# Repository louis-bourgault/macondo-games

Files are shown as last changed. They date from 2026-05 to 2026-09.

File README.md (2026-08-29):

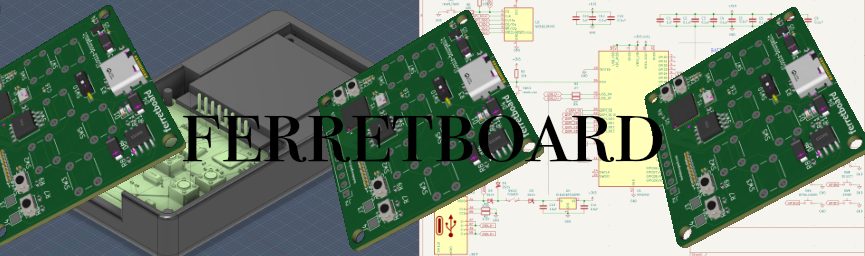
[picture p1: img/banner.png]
banner

# ferretboard!!!

> [!IMPORTANT]
> # PLEASE READ
> The primary documentation for this project can be found at [ferretboard.louisbourgault.com/docs](https://ferretboard.louisbourgault.com/docs). Please read from that source for organised information on software interfaces, assembly, and a more complete project overview.
> 
> This README remains the authoritative source on commands to build the firmware for the device, and also has a nice image gallery at the end.



# What is this?
Ferretboard is a simple games console, made to be easy to program and cheap to produce. Version one uses a RP2040 MCU; version two, currently in development, upgrades this to the RP2350 and changes the form factor significantly. The display is a 240x240 1.54" LCD, which is common and cost effective. It is battery powered, using a basic 3.7v LiPo.

The idea for this project, in the long term, is to be an easy introduction to programming and game development for students. The micropython sdk is editable in web, easy to get started using, and would be perfect in the long run for a classroom setting or Hack Club larger program. The upgrade to the RP2350 will make this level of software possible, with more RAM and processing power to make running complicated games within Micropython possible. 

The overall dimensions of the build are around 100x50mm for both v1 and v2, with a depth of around 20mm. The case is 3d printed.

This is made as a part of Hack Club Macondo. You can find my project at [macondo.hackclub.com/projects/1137](https://macondo.hackclub.com/projects/1137). Thank you to Hack Club for financing and helping me with this project. You can find all acknowledgements for this project at [ferretboard.louisbourgault.com/thanks](https://ferretboard.louisbourgault.com/thanks)

## Online stuff!
Docs site and main site: [ferretboard.louisbourgault.com](https://ferretboard.louisbourgault.com)
Web editor for the micropython sdk: [editor.louisbourgault.com](https://editor.louisbourgault.com)

## Project Structure
See at [ferretboard.louisbourgault.com/docs/structure](https://ferretboard.louisbourgault.com/docs/structure)

# Building Firmware
There's quite a few different firmwares at this point to build. Docs on how to do each of them:

[Original Go System](https://ferretboard.louisbourgault.com/docs/go-building)
[New micropython system (embedded into Go)](https://ferretboard.louisbourgault.com/docs/micropython-building)
[Old micropython system](https://ferretboard.louisbourgault.com/docs/oldmp-build)

To flash firmware on v2, hold down the reset button and reboot the device. On v1, manually short QSPI_SS and GND with tweezers and then reboot. The easiest access points for this are the first and last pins of the flash chip on the top side - you can just pinch the top of the flash chip, and that should do it.

Then, either use picotool over command line, or just drag the uf2 file into the RPI-RP2 volume that shows up in Finder/File Explorer/Dolphin/whatever you use.

# Assembly instructions
Assembly instructions can be found at [ferretboard.louisbourgault.com/docs/assembly](https://ferretboard.louisbourgault.com/docs/assembly).

# Gallery

The full gallery can be found at [ferretboard.louisbourgault.com/gallery](https://ferretboard.louisbourgault.com/gallery). Here is just a few sample images: 

## The micropython online editor working!
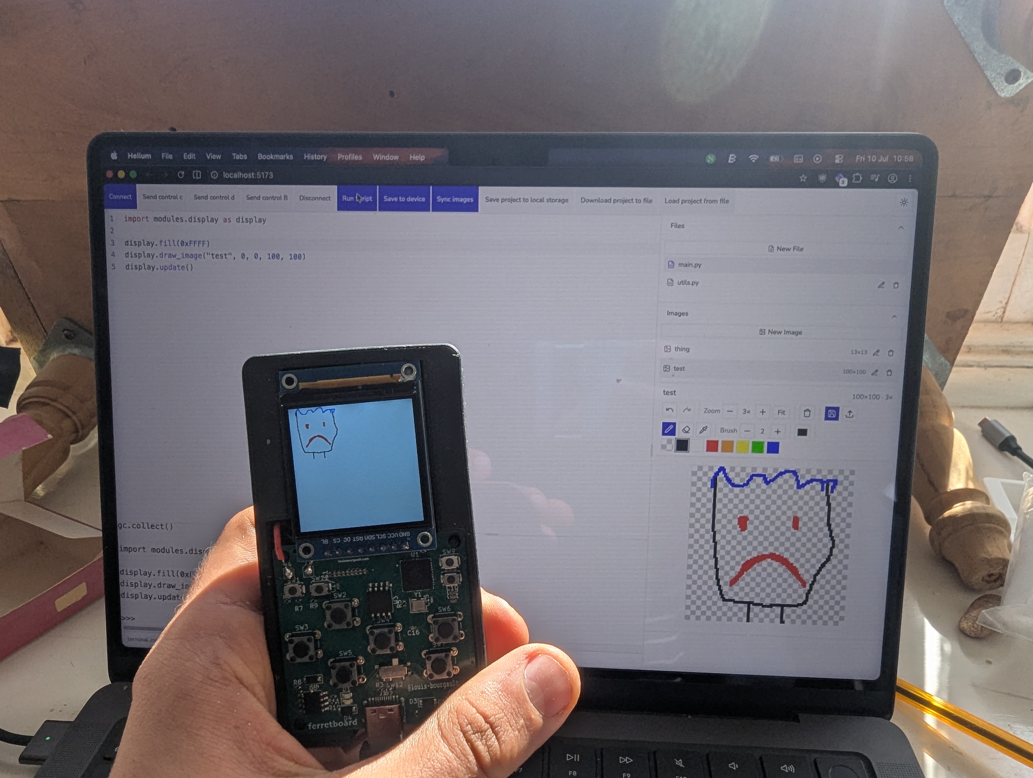
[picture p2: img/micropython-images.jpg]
micropython image system


## Finished Device (v1)
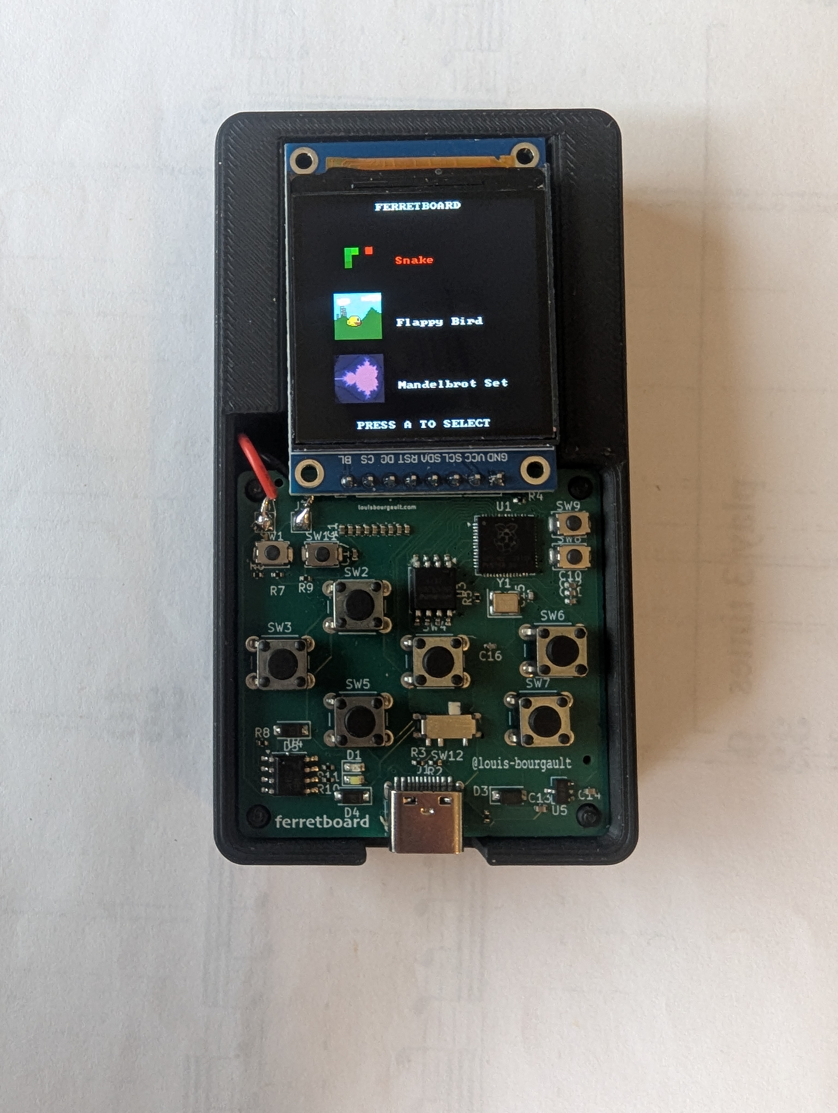
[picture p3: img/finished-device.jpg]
Finished device


## Fusion design for new version (not produced yet)
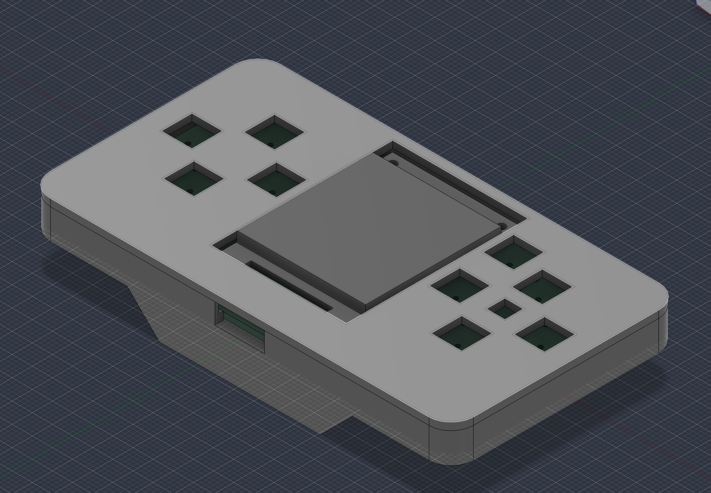
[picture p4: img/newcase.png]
New Version


# Acknowledgements

Find all acknowledgements at [ferretboard.louisbourgault.com/thanks](https://ferretboard.louisbourgault.com/thanks)

Font file used in /software/helpers/text.go - Public Domain, [github.com/dhepper/font8x8](https://github.com/dhepper/font8x8/blob/master/font8x8_basic.h)

framebuf2 - MIT Licenced, https://github.com/peter-l5/framebuf2

codemirror v6 - MIT Licenced, https://code.haverbeke.berlin/codemirror/dev/ 

# Licensing

This project is dual-licensed:
* **Hardware:** The schematic, PCB layout, and documentation files are licensed under the [CERN Open Hardware Licence v2 - Strongly Reciprocal (CERN-OHL-S-2.0)](./mini-games/LICENSE.txt). If you modify and distribute this hardware, you must share your changes to it. 
* **Firmware/Software:** All source code is licensed under the [GNU AGPLv3](./LICENSE.txt). You can't copy and distribute a changed version of this without making your modifications public, including distribution by serving a part of this code over a network. [Even if you're Bambu Labs.](https://consumerrights.wiki/w/Bambu_Lab_cease_and_desist_against_OrcaSlicer_fork_developer)

# Looking for something?
Looking for something, like assembly instructions or something else? Please check the link up the top of this readme.

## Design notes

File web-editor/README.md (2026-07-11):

# Web Editor
This repository is a feature complete web editor for the python sdk of the board, which includes a multifile code editor (based on the excellent codemirror library), image sprite editor with transparency, and terminal. The system connects to the device over USB using the browser WebSerial API.

## Stack

This web app uses a simple typescript setup comprising of:
- Svelte
- Sveltekit
- UI library: shadcn-svelte
- codemirror

There is no database or backend component, and this can be entirely run statically by building sveltekit to the static adapter.

To program a device using this sdk, you must have a device flashed with the micropython sdk, which can be found at /mp-sdk at the top level of this repository. Follow the instructions in that README for instructions on building and flashing this firmware.

## Running locally

Install modules and run:

```bash
pnpm install

pnpm run dev
```

Then open your browser to localhost:5173 to test.

## Requirements
The web serial api is not supported by Safari or Firefox. Use a recent version of a chromium based browser.

## Licence
As with all other code components in this repository, this module is licenced under the [GNU AGPL](../LICENSE.txt)

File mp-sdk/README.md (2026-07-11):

# uploading to the device
it doesn't work just hitting run in vs code: hit all commands and then do micropico: upload project to pico from command/control shift p

# Building instructions:
## Setup - what you need installed on your computer (macOS, likely very similar on linux, if you're on windows use WSL)
If you're on linux, all you'll need to change is to install the packages below with your distro's package manager

```zsh
brew install --cask gcc-arm-embedded
brew install cmake ninja
```

next, clone the micropython git repository and compile some things

```zsh
git clone https://github.com/micropython/micropython.git
cd micropython
make -C mpy-cross

cd ports/rp2
make submodules
```

Note: once you're at this stage, you can use the script ```build.sh``` in this repository to build it. Note, you will have to adapt this script to where everything is on your machine, so its probably easier to just do the commands manually.

## Building
Hop into the ```ports/rp2``` directory inside your micropython git clone.

```zsh
# delete old build cache
rm -rf build-ferretboard

#run the build command with paths to the board directory and the manifest.py. For me this is
make BOARD_DIR=/Users/louisb/Documents/hardware/macondo-games/mp-sdk/boards/ferretboard FROZEN_MANIFEST=/Users/louisb/Documents/hardware/macondo-games/mp-sdk/boards/ferretboard/manifest.py

```

This will output a uf2 file in the ```ports/rp2/build-ferretboard/``` directory inside the micropython repo, which you can then copy onto the device. If you're using the script as i am, it will instead copy it directly into this repository.

# Licences
This software itself is AGPL licenced. 

Acknowledgement is also given to the framebuf2 library, which makes up an integral part of this repository. This component is licenced under a MIT licence.

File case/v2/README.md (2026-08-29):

## The files in here:

- casev2.f3d/.step - the case, on its own. does not include cad model of screen or pcb
- st7789_display.f3d/.step - model of the display that I use. Took me a decent amount of time to model, so i'm including it.
- fbv2_including_pcb_and_screen.f3z - an archive file including all the component parts. this uses multiple fusion files from seperate components, as well as the PCB, imported from Kicad. What all the screenshots are of, but not neccesary for the case design - hence no step files. Also, multi file exports get annoying from Fusion
- 3dp/ - the production STL files for the upper and lower sections of the case. Put these into your slicer.

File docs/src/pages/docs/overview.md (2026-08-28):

---
layout: '../../layouts/DocsLayout.astro'
title: 'Project Overview'
draft: false
category: "general"
---

# Ferretboard!!!

Ferretboard is a small games console based around a custom pcb and a 1.54" SPI display. Version one uses the RP2040 chip. Version two is currently in development, and upgrades this to the RP2350 with a significantly different board and case. The overall dimensions of both versions are around 50x100x20mm, so a relatively typical size for a handheld.

This device is being made as part of Hack Club Macondo (which is awesome). You can find it at [macondo.hackclub.com/projects/1137](https://macondo.hackclub.com/projects/1137).

Another major element of this project is that the Go game system is also compatible with being built for web assembly. A demo of this can be found at the root of this website.

## Components
The finished version one system is made up of a custom pcb, including the RP2040 chip, 16MB of flash memory, and a battery management circuit. It also uses:
- 3.7v 1000mAh LiPo
- 1.54" LCD Screen of pixel dimensions 240x240 and with an SPI interface
- 6 basic 6x6x5 push to make switches for the d-pad, A and B
- 2 smaller buttons on the assembled pcb for Start and Exit
- 3d printed case, the stl file for which is in ```/case/v1/case.stl``` in the repository

The version two KiCad project can be found in ```/hardware-v2```, and its case files are in ```/case/v2```. It is still a work in progress, so the assembly instructions are for version one unless they specifically say otherwise.

## Controls
The system has a basic d-pad, as well as A and B buttons as the primary controls. There are also two buttons (called Start and Exit in software) for other purposes, but it is better to not use them as primary game controls since they are smaller and more annoying to access.

For the WASM version, these are mapped to:
| Button | Key |
| --- | --- |
| D-Pad  | WASD |
| A | J |
| B | K |
| Start | Enter |
| Exit | Shift |

## Constraints
The RP2040 has its hardware constraints, although most games will fit very comfortably within them. It is a dual core cpu rated for 133MHz, with 264KB of SRAM. A considerable amount of this ram is used for the display buffer: 115,200 bytes, or 112.5KiB, since we use full 16 bit colour. This leaves around 149KiB before the rest of the firmware and runtime allocations are taken into account.

Another constraint that I discovered through working on this is that the RP2040 does not have a FPU (floating point unit). This means that it takes a ton of cpu cycles to do any float division and multiplication, so we need to make sure to stay with integers for as much as possible.
This is a problem for maths visualisations like the Mandelbrot and Julia set, which probably will not run very well, if at all, on the actual device unless optimised further.

The flash storage is 16MB. The current embedded MicroPython firmware reserves the last 8MB for its LittleFS filesystem, with the first 8MB left for the firmware. There is plenty of overall flash for this kind of project, but individual MicroPython source files and images have smaller limits that are explained in the MicroPython reference.

## This website
This website is made with Astro, and no external libraries, and can be found in the ```/docs``` folder of the repository.

## Acknowledgements
Font file used in /software/internal/helpers/text.go: [github.com/dhepper/font8x8](https://github.com/dhepper/font8x8/blob/master/font8x8_basic.h). (Public domain)

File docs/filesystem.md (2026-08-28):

# The Ferretboard Filesystem

The Ferretboard runs a LittleFS2 volume at `/` on the last 8 MiB of its
16 MiB QSPI flash. Students see it as plain Python files:

```python
>>> f = open("hello.txt", "w")
>>> f.write("hello ferret")
>>> f.close()
>>> print(open("hello.txt").read())
```

This document explains how that works: the flash layout, the layers between
`open()` and the silicon, and the gotchas that had to be solved to get there.

## Architecture

The firmware is Go (TinyGo, RP2040/RP2350) hosting a MicroPython interpreter.
Go owns the hardware; MicroPython owns the student-facing runtime. The
filesystem spans that boundary:

```
Python  open() / os.listdir()
   │
   ▼
MicroPython VFS layer                 (extmod/vfs.c)
   ▼
VfsLfs2 driver                         (extmod/vfs_lfs.c — LittleFS2)
   │  readblocks / writeblocks / ioctl
   ▼
"Flash" block device object           (port/flash_storage.c)
   │  ferret_flash_read/write/erase/block_count/block_size  (//export)
   ▼
Go flashBlockDev                      (flash_common.go)
   │  ReadAt / WriteAt / EraseBlocks / Size
   ▼
raw flash backend
   ├─ device: machine.Flash           (flash_device.go — bootrom flash API)
   └─ host:   file-backed stub        (flash_stub.go  — NOR emulation)
```

## Flash layout

The chip is a 16 MiB W25Q128-class QSPI flash, memory-mapped at
`0x1000_0000` (XIP). The image is laid out as:

| Region | XIP address | Notes |
|---|---|---|
| boot2 | `0x1000_0100` | 256 bytes, second-stage bootloader |
| firmware (code+data) | `0x1000_0100` + | ~330 KB |
| **filesystem** | last 8 MiB of chip | 2048 blocks × 4 KiB |

The boundary between firmware and filesystem is computed at runtime, not
hard-coded:

- TinyGo's linker (`targets/arm.ld`) defines `__flash_data_start` (end of the
  program image) and `__flash_data_end` (end of the whole flash window) from
  `__flash_size`.
- `setupFlashRegion()` (`flash_device.go`) reads those symbols via
  `machine.FlashDataStart()/FlashDataEnd()` and places the FS region at
  `regionBase = rawTotalSize - 8 MiB`, i.e. ~7.6 MiB into the chip.

`__flash_size` comes from the target JSON. This is important:

```json
// ferretboard.json
"ldflags": ["--defsym=__flash_size=16M"]
```

`just device` builds with `-target ferretboard.json`. The stock `pico` target
uses `__flash_size=2048K`, which makes `regionBase` negative — the firmware
panics with "firmware larger than first 8 MiB of flash" before the REPL ever
appears (symptom: no serial output at all; the boot delay + stage traces we
added temporarily made it visible).

## Block device (Go side)

`flashBlockDev` (`flash_common.go`) presents the FS region as a zero-based
block device with 4 KiB blocks, hiding `regionBase` from its consumers. The
4 KiB size matches the flash erase sector, so LittleFS2 operations align with
hardware erases.

Key constants:

```go
flashBlockSize   = 4096   // erase sector == LFS2 block
flashStorageBytes = 8 MiB // reserved FS region
writePage        = 256    // NOR page-program granularity
```

`WriteAt` pads partial writes to whole 256-byte pages with `0xFF` before
calling the raw backend (`flash_common.go:76`). This is safe because NOR
programming only clears bits and LittleFS2 only writes into erased sectors,
so padding bytes are always `0xFF` no-ops.

### Device backend — `machine.Flash`

TinyGo's RP2040 flash driver (`machine_rp2_flash.go`):

- `ReadAt`: reads the memory-mapped XIP window directly (`unsafe.Slice` over
  `0x1000_0000 + off`).
- `WriteAt` / `EraseBlocks`: call the bootrom's `flash_range_program` /
  `flash_range_erase` tables (`machine_rp2040_rom.go`). The bootrom functions
  must run from RAM, which the driver handles; they also flush the XIP cache.

### Host backend — `stubbedFlash`

The PC reference build (`just host`) models the chip as a plain file
(`build/ferret.img`, overridable with `FERRET_FS_IMAGE`), initialised to
`0xFF` so erased reads behave like real flash. It is a debugging tool, so it
emulates NOR semantics faithfully:

- `WriteAt` does a read-modify-**AND**: programming a byte yields
  `existing & new`. A plain file overwrite would corrupt data, because
  LittleFS2 programmes a 4 KiB block in several 256-byte page-prog calls and
  the later ones would clobber the earlier ones. This exact bug corrupted the
  volume during development (formatted fine, then `open()` returned garbage
  or the mount failed after writes).
- `EraseBlocks` fills with `0xFF`.

## MicroPython side (C)

`port/flash_storage.c` wraps the `//export` funcs in an MP block device
object (`Flash` with `readblocks`/`writeblocks`/`ioctl`) and bootstraps the
volume:

```c
void ferret_fs_init(void) {
    if (!ferret_flash_has_fs()) {
        ferret_fs_format();       // first boot only
    }
    mp_obj_t bdev = ...&ferret_flash_obj;
    args[0] = mp_call_function_n_kw(&mp_type_vfs_lfs2, 1, 0, &bdev);
    args[1] = MP_OBJ_NEW_QSTR(qstr_from_str("/"));
    mp_vfs_mount(2, args, &mp_const_empty_map);
}
```

- **First-boot detection**: `ferret_flash_has_fs()` reads block 0 and checks
  for the `"littlefs"` superblock name at offset 8. A blank chip (all `0xFF`)
  has none, so it is formatted with `lfs2_format` first.
- **Mounting**: `VfsLfs2`'s `make_new` mounts eagerly, so instantiating
  `VfsLfs2(flash)` and passing it to `mp_vfs_mount("/", ...)` does the whole
  job. `mp_vfs_lfs2_make_new` is `static` in `vfs_lfs.c`, hence the
  roundabout `mp_call_function_n_kw` on the type object.
- **Soft reset**: `run_repl()` (host.c) re-runs `mp_embed_init` → registers
  the `ferret` module → `ferret_fs_init()` on every Ctrl-D, re-mounting `/`
  on the same volume.

The `ioctl` handler returns `BLOCK_COUNT`/`BLOCK_SIZE` from the Go exports
and `0` for INIT/DEINIT/SYNC. `readblocks`/`writeblocks` accept the optional
offset argument (block-level + sub-block offset) — both are summed correctly
in `ferret_flash_read/write` (`block*4096 + off`), no double counting.

## Boot flow (device)

```
bootrom → boot2 → Reset_Handler
  → runtime.init()          USB CDC enumerates here (before main!)
  → main()                  display init
  → setupFlashRegion()      FS region math (needs __flash_size=16M)
  → ferret_boot()           point MP's GC at mpHeap
  → run_repl()
      mp_embed_init
      register_ferret_module
      ferret_fs_init()      detect/format/mount "/"
      pyexec_friendly_repl  ">>> " banner
```

The REPL prompt only appears after the volume is mounted. If the mount
fails, the board looks dead even though USB is fine.

## Building and testing

```sh
# PC reference build — interactive MP REPL over a file-backed flash image
just host   # -> ./spike

# Device build — 16 MiB target, LittleFS2 region at ~7.6 MiB
just device # -> ferret.uf2  (flash with: picotool load ferret.uf2 -f)
```

`MICROPYTHON_ROOT=/path/to/micropython` must be set (the justfile's
`mp-arm`/`mp-host` recipes regenerate the embed package, genhdr and the
`libmp_embed*.a` archives; `gen_cgo.sh` bakes the archive fingerprints into
`z_cgo_link_*.go` — it re-runs after `ar rcs` so Go's build cache never
links a stale archive).

## Gotchas discovered along the way

1. **Wrong `__flash_size` (the "no serial at all" bug).** Building with the
   stock `pico` target (2 MiB) while the region math assumes 16 MiB made
   `regionBase` negative → immediate panic, before any USB output appeared.
   Fix: build with `ferretboard.json` (`__flash_size=16M`).
2. **TinyGo interp panic.** `machine.FlashDataStart()/End()` inside an
   `init()` function made the compile-time interpreter fold the
   `__flash_data_end` pointer constant and panic ("cannot convert pointer
   value to byte"). Fix: call them from `main()` via `setupFlashRegion()`
   — the interp only folds `*.init` functions.
3. **`mp_call_method_n_kw` hang.** Instantiating `VfsLfs2` must use
   `mp_call_function_n_kw(&mp_type_vfs_lfs2, 1, 0, &bdev)`, not
   `mp_call_method_n_kw` (which treated `&mp_type_vfs_lfs2` as a `self` and
   hung at boot).
4. **`ioctl` arity.** `t_flash_ioctl` must be `FUN_OBJ_3` (it takes
   self/cmd/arg); `FUN_OBJ_2` left the arg slot unset and `BLOCK_COUNT`
   returned garbage → mount failed.
5. **Probe offset.** The LFS2 superblock magic/name sits at offset 8 of
   block 0, not 16 — an off-by-one made every boot think the volume was
   unformatted and re-format it (data loss on every reboot).
6. **NOR write semantics (host).** The stub's plain-file overwrite did not
   emulate "program only clears bits", so padded page-progs clobbered
   earlier progs in the same 4 KiB block. Fixed with read-modify-AND.
7. **Fingerprint ordering.** `gen_cgo.sh` ran before the archives were
   rebuilt, so its md5 was one build behind; Go's cache then linked stale
   C objects. Fixed by re-running it after `ar rcs` in `mp-arm`/`mp-host`.

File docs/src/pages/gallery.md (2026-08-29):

---
layout: '../layouts/DocsLayout.astro'
Title: Image Gallery
draft: false
---

# V1 design

schematic

finished device

fusion case design

with parts included

case, but in white

jlc design

# SDK on web

images in the sdk, working on the device

# Version Two

new case

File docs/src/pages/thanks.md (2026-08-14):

---
layout: '../layouts/DocsLayout.astro'
Title: Thanks and Acknowledgements
draft: false
---

# Thanks and Acknowledgements
## Hack Club
The biggest acknowledgement here. I made this for Hack Club Macondo, an awesome hackathon. They funded the build, and even bought me rewards for the hours i put in.
Hack club helps teens learn to do coding and electronics.
[https://hackclub.com](https://hackclub.com)

## Open Source
Font file used in /software/helpers/text.go - Public Domain, [github.com/dhepper/font8x8](https://github.com/dhepper/font8x8/blob/master/font8x8_basic.h)

framebuf2 - MIT Licenced, https://github.com/peter-l5/framebuf2

codemirror v6 - MIT Licenced, https://code.haverbeke.berlin/codemirror/dev/

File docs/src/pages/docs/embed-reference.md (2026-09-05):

---
layout: '../../layouts/DocsLayout.astro'
title: 'MicroPython SDK - Embedded Reference'
draft: false
category: "mp"
---

The firmware exposes a single ```ferret``` module with all drawing, input and
helper functions built in. Import it at the top of your game script with:

```python
import ferret
```

All colours are RGB565 integers; use ```ferret.rgb_to_565(r, g, b)``` to build
one from 8-bit channels. The screen is 240x240 pixels.

## Drawing

Drawing calls update a frame buffer in RAM. Call ```ferret.present()``` to
send it to the screen.

### ```ferret.pixel```
Arguments: x, y, colour.

Draws a single pixel.

### ```ferret.fill_rect```
Arguments: x, y (top left corner), width, height, colour.

Draws a filled rectangle.

### ```ferret.fill```
Argument: colour.

Fills the whole screen with a single colour. Useful to clear the frame
between frames.

### ```ferret.draw_text```
Arguments: text, x, y, colour.

Draws text at the top-left coordinate x, y. A single character is 8x8.

### ```ferret.measure_text```
Argument: text. Returns (width, height).

Measures the space text will take up, so you can centre it.

### ```ferret.draw_image```
Arguments: image_name, x, y.

Draws an image stored on the device at (x, y). The size is read from the image
manifest, so sync your images from the web editor first. Transparent pixels use
the RGB565 chroma key colour ```0xF81F``` and are skipped (if you are using the 
web editor, this is done automatically for transparent pixels). No image can be
over 240x240 pixels.

### ```ferret.present```
No arguments.

Flushes the frame buffer to the display.

## Input

Call ```ferret.input_update()``` once per frame **before** checking buttons.
Key names are strings. Both boards provide "A", "B", "UP", "DOWN", "LEFT"
and "RIGHT". Version one additionally provides "START" and "EXIT"; version
two provides "X", "Y" and "MENU" instead.

### ```ferret.input_is_pressed```
Argument: key name. Returns a bool.

True if the key is currently held.

### ```ferret.input_was_just_pressed```
Argument: key name. Returns a bool.

True if the key is pressed this frame but was not last frame.

### ```ferret.input_was_just_released```
Argument: key name. Returns a bool.

True if the key was pressed last frame but is not this frame.

## Helpers

### ```ferret.rgb_to_565```
Arguments: r, g, b. Returns an RGB565 colour.

### ```ferret.random_int```
Arguments: min, max. Returns a random integer in the inclusive range [min, max].

## Example

```python
import ferret

while True:
    ferret.input_update()
    if ferret.input_was_just_pressed("A"):
        ferret.fill(ferret.rgb_to_565(255, 0, 0))
        ferret.present()
```

## Files and editor functions (not user facing, you should not need these)

The editor also uses ```ferret.write_file_b64```, ```ferret.append_file_b64```,
```ferret.file_manifest```, ```ferret.delete_file```,
```ferret.write_image```, ```ferret.append_image```,
```ferret.write_image_end```, ```ferret.image_manifest``` and
```ferret.delete_image``` to save code and sync images. Games do not normally
need to call these functions themselves. A single file is currently limited to
16KiB. Normal Python ```open()``` and ```os``` filesystem access is not included.

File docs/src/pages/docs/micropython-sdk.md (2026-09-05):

---
layout: '../../layouts/DocsLayout.astro'
title: 'MicroPython SDK (new) - About'
draft: false
category: "mp"
---

The current MicroPython SDK is the main scripting system for the console. You write your code in the web editor at ```/web-editor``` in the repository, which is deployed at [editor.louisbourgault.com](https://editor.louisbourgault.com).

The intention of this system is to provide an easy entry to the console. I am first writing this with my idea being to give these devices to a school as a way to teach students to code, or at least to pitch the idea to a teacher. I think that having an easy to code system that runs fully in a browser without having to install anything is pretty cool, personally.

This is different to the [legacy MicroPython SDK](/docs/micropython-sdk-legacy). The current firmware has a Go backend which controls the display, input and filesystem, with MicroPython embedded into it and a thin C glue layer in the middle. Student programs use the ```ferret``` module to call into that backend.

## Using the editor

The editor uses Web Serial, so you need a recent Chromium-based browser such as Chrome or Edge, and the page must be loaded over HTTPS or localhost. Safari and Firefox do not currently support Web Serial.

Every project has a ```main.py``` file, which is run automatically when the device starts or soft resets. Other ```.py``` files can be imported from ```main.py```. Their names must be valid Python identifiers followed by ```.py``` (for example, ```player.py```). Start programs by importing the SDK:

```python
import ferret
```

The editor can create multiple code files, draw and import images, show the serial terminal, save a project in browser storage, and download or load the complete project as a JSON file. Connect the device, then use **Run Script** to synchronize the project's code files to flash (including removing files deleted or renamed in the editor) and soft reset into the new ```main.py```. Images are sent separately with **Sync Images**.

See the [embedded reference](/docs/embed-reference) for the functions available to games, and the [building guide](/docs/micropython-building) for making the firmware itself.

## Included Python modules

The firmware intentionally includes a fairly small set of Python modules. The most useful ones for games are ```time```, ```math```, ```struct```, ```array```, ```collections```, ```gc``` and ```sys```. Normal Python filesystem functions such as ```open()``` and ```os.listdir()``` are not included in the current system; code and images are managed by the Go backend and the web editor.

images in the sdk, working on the device

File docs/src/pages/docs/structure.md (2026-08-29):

---
layout: '../../layouts/DocsLayout.astro'
title: 'Project Structure'
draft: false
category: "general"
---

## File structure

## Project Structure
- /software - all software for the Go game system and the current embedded MicroPython firmware
- /software/cmd/embed - the current Go-hosts-MicroPython firmware and its build system
- /mini-games - The kicad project and files for the version one hardware
- /hardware-v2 - The kicad project and files for the version two RP2350 hardware, which is still in development. Its JLC files are under /hardware-v2/jlcpcb/production_files.
- /case - files for making the cases. Version one and version two are in their own subdirectories.
- /img - the images used in the main readme
- /docs - this website
- /mp-sdk - the legacy MicroPython SDK and its custom MicroPython board definition
- /mp-embedding - an early experiment used while working out how to embed MicroPython into Go
- /web-editor - the web editor for the current embedded MicroPython SDK.

Production files: production files can be found at /jlcpcb/production-files in both the mini-games and hardware-v2 directories, for the v1 and v2 design respectively. These are automatically generated with the jlcpcb tools plugin in kicad, and use LCSC numbers for BOM and CPL. 

Big thanks to the plugin: [Bouni/kicad-jlcpcb-tools](https://github.com/Bouni/kicad-jlcpcb-tools)

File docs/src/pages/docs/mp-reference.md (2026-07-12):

---
layout: '../../layouts/DocsLayout.astro'
title: 'Micropython SDK - Quick Reference'
draft: false
category: "mp"
---

The micropython sdk contains two main modules - ```modules.display``` and ```modules.input```. Import them at the top of your file with:

```python
import modules.display as display
import modules.input as input
```

## Display

### General shape
To make changes to the display, call the following functions to update the frame buffer in RAM. Then call ```display.update()``` to send the data to the screen.

All colours are in RGB565 format.

### ```display.pixel```
Arguments: x, y, colour.

Draws a single pixel to the screen

### ```display.rect```
Arguments: x, y (top left corner), width, height, colour.

Draws a rectangle to the screen

### ```display.text```
Arguments: text, x, y, colour

Draws text to the screen at top left coords of x and y. A single character is size 8x8.

### ```display.draw_image```
Arguments: image_name, x, y, image_width, image_height

Draws an image stored in ```/img``` in the device's flash to the screen. As of now, the logic cannot infer the image width and height, so you must explicitly pass them. This my change in future.
When you upload an image from the web editor, it is automatically placed in this directory.

### ```display.update```
No arguments.

Flushes data to the display.

## Input
The input module deals with button presses. 

### General shape
Call ```input.update``` to check all the buttons, and update state (this includes moving the store of current button presses to last button presses). Call this **before** you do any input handling in your main game loop

Key names are strings, and are "A", "B", "UP", "DOWN", "LEFT" and "RIGHT"

### ```input.is_pressed```
Argument: key name

Returns a boolean on whether it is currently pressed

### ```input.was_just_pressed```
Argument: key name

Returns true if the key is pressed this frame but was not last frame.

### ```input.was_just_released```
Argument: key name

Returns true if the key was pressed last frame but was not this frame.

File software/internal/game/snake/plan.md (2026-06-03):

# What is this?
A plan on how to code snake. I want to try and figure out the logic without any copilot or anything.
i want this to be more efficient than it needs to be. 

main struct
- current direction
- slice of {x,y} coordinates
  - can't use normal slices since we'll be constantly adding to the end and taking away from the start, and exhaust ram by just moving the pointer forwards a ton
  - apparently a ring buffer is a thing. I think i'll choose this - it comes out to 1.1kb of ram for the whole thing
  - linked list

params
- board width: 24*24, cells 10 pixels each

color 
- changes colour depending on which level it is in

rgb565 colours - format of RRRRRGGGGGGBBBBB where each one is a number

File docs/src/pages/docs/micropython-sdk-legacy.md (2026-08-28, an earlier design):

---
layout: '../../layouts/DocsLayout.astro'
title: 'MicroPython SDK (legacy) - About'
draft: false
category: "ogmp"
---

Apart from the golang sdk, there is also a micropython sdk. This is designed for ease of use, even to go so far as to be an introduction to programming.
This came about after I showed this project to a digital technologies teacher at my school, and he was somewhat interested in how something like the device could be used in a school setting due to its simplicity and people being able to make something that they can actually hold in their hands in a relatively limited amount of time. However, coding in Go doesn't really work for this: it's not that beginner friendly a language (for someone who's never coded before, at least), and more importantly there would be a significant amount of software that would need to be installed on the computers for people to even start working on it, including VS code and the compiler.

So I made a simple micropython sdk that was programmed through an earlier version of the web editor.

Note: this is the old version of the mp-sdk. The current deployed editor uses the [new embedded SDK](/docs/micropython-sdk), so it should not be used with this firmware.

## Building the micropython sdk.
You will need an Arm GCC toolchain, cmake and ninja. On macOS, I installed them with:

```sh
brew install --cask gcc-arm-embedded
brew install cmake ninja
```

Then clone MicroPython and prepare its RP2 port:

```sh
git clone https://github.com/micropython/micropython.git
cd micropython
make -C mpy-cross
cd ports/rp2
make submodules
```

From ```ports/rp2```, build using the board and manifest from this repository. Replace ```/path/to/macondo-games``` with the real path to your clone:

```sh
make BOARD_DIR=/path/to/macondo-games/mp-sdk/boards/ferretboard \
  FROZEN_MANIFEST=/path/to/macondo-games/mp-sdk/boards/ferretboard/manifest.py
```

This creates the legacy UF2 in MicroPython's ```ports/rp2/build-ferretboard``` directory.

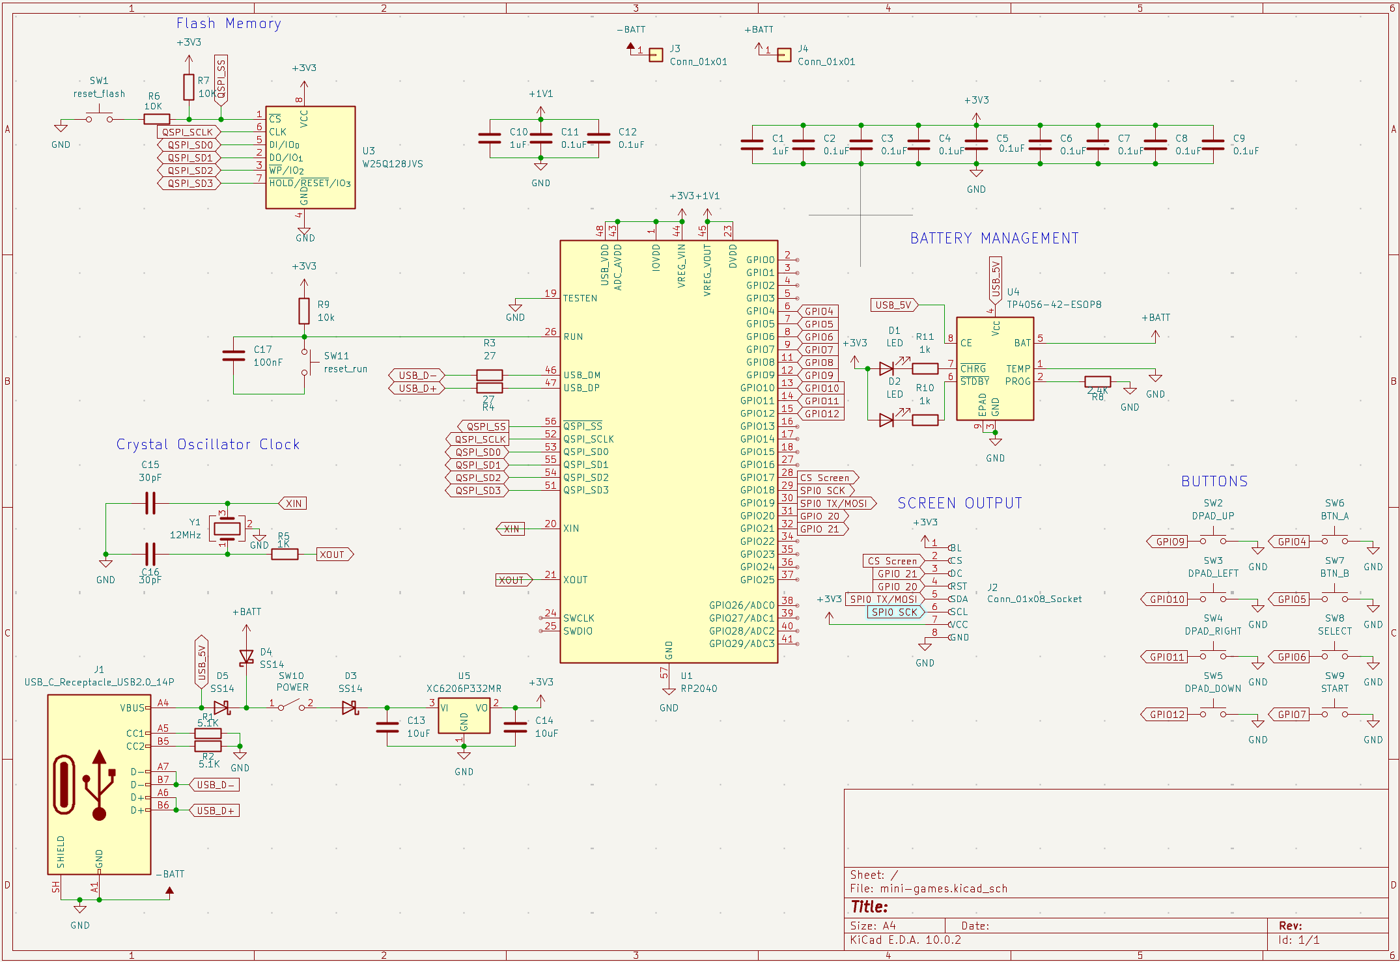
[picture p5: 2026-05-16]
img/Schematic.png

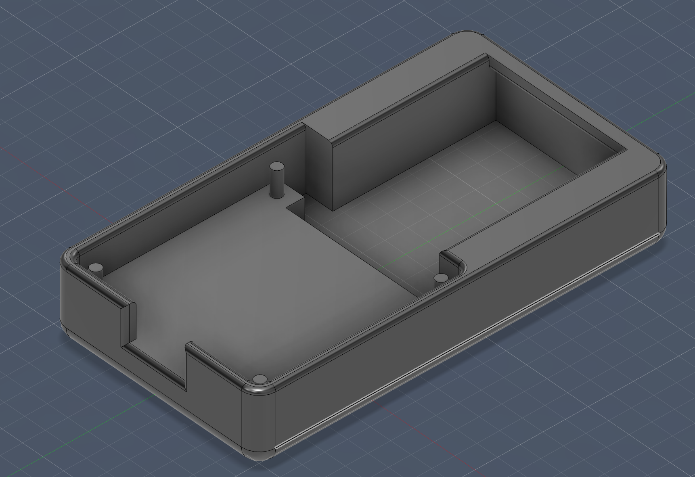
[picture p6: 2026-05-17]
img/fusion-case.png

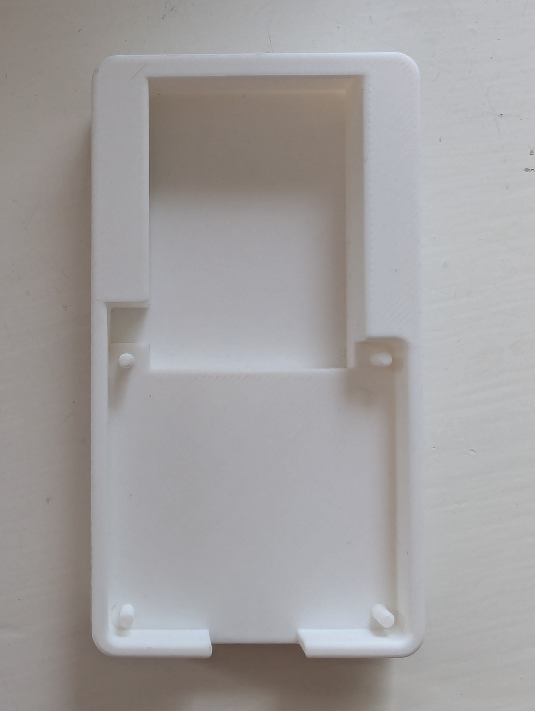
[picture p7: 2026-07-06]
img/whitecase.jpg

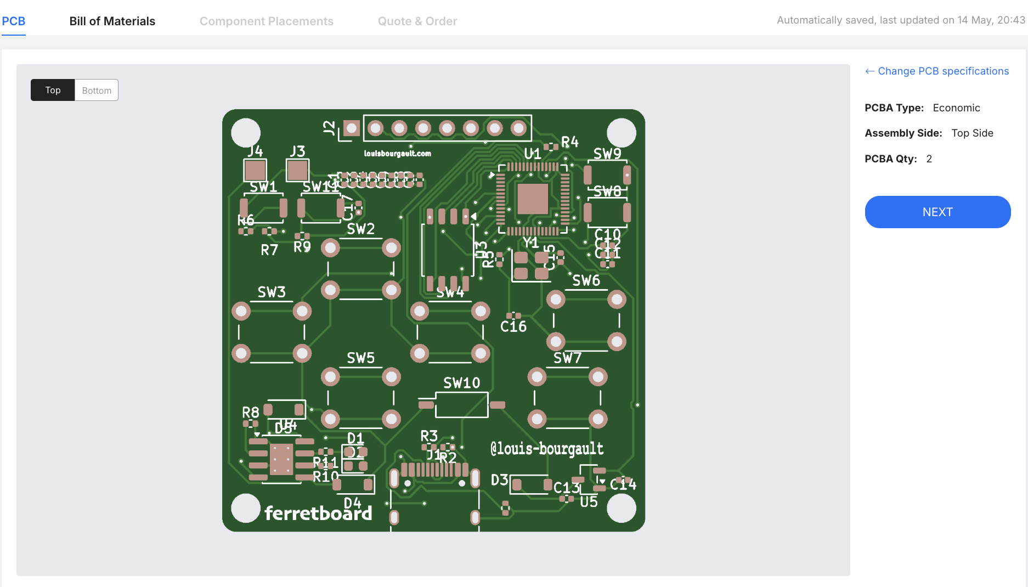
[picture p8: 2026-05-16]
img/JLC-Topside.png

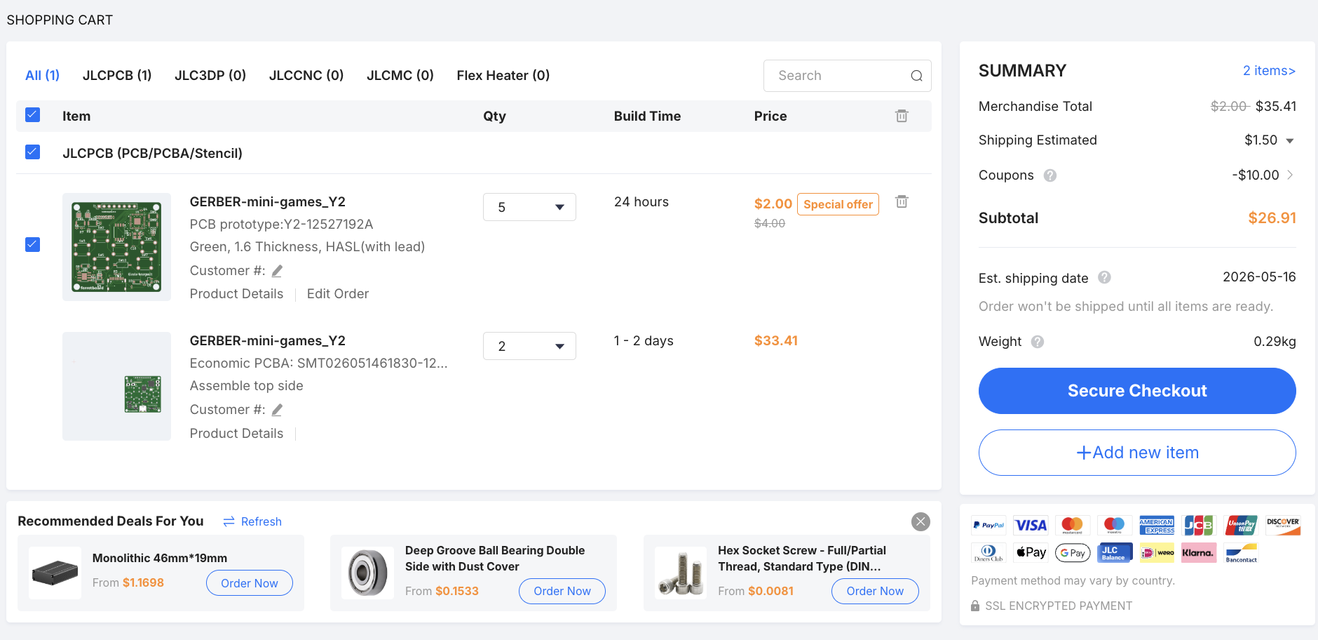
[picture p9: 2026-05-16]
img/JLC-Cart.png

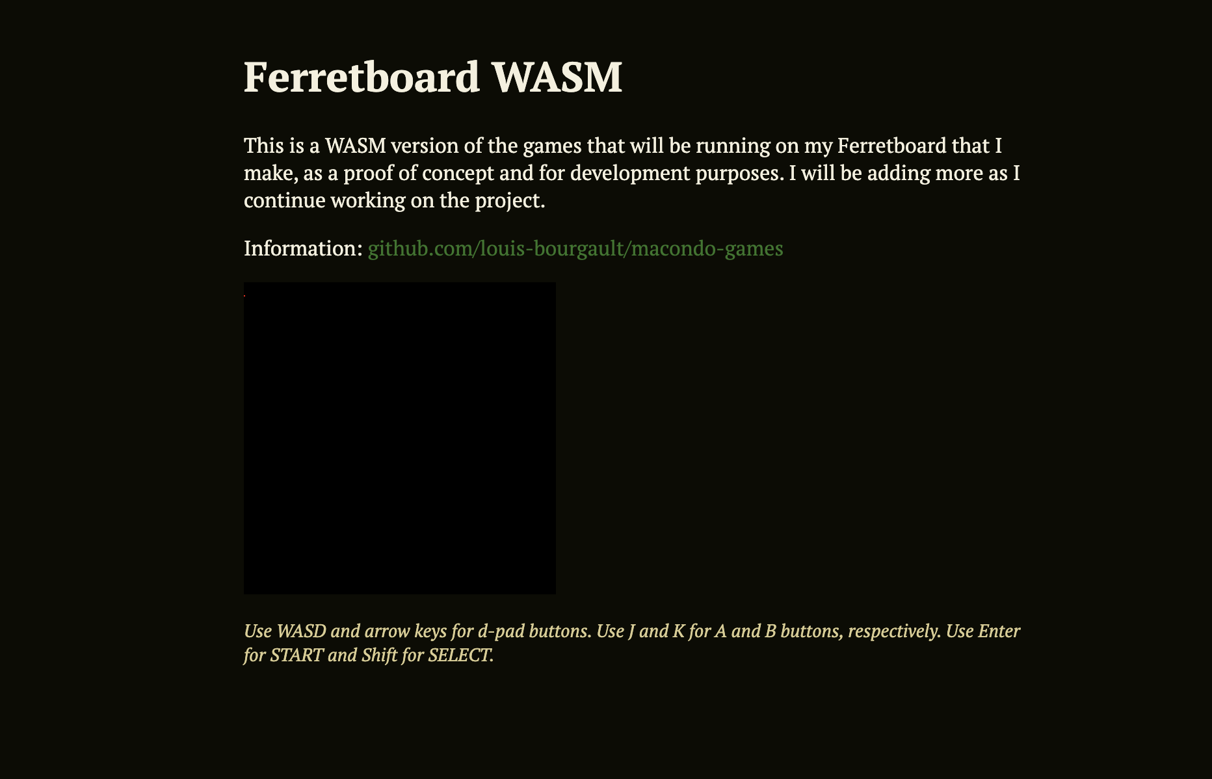
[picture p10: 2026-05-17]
img/web-version.png

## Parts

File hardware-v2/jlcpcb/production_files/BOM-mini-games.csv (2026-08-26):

Comment | Designator | Footprint | LCSC | Quantity
0.1u | C10 | C_0402_1005Metric | C1525 | 1
0.1uF | C2,C3,C4,C5,C6,C7,C9 | C_0402_1005Metric | C1525 | 7
100n | C11,C12 | C_0402_1005Metric | C1525 | 2
10K | R7 | R_0402_1005Metric | C25744 | 1
10uF | C13,C14 | C_0402_1005Metric | C15525 | 2
15pF | C15,C16 | C_0402_1005Metric | C1548 | 2
1K | R5 | R_0402_1005Metric | C11702 | 1
1k | R10,R11 | R_0402_1005Metric | C11702 | 2
1uF | C1 | C_0402_1005Metric | C52923 | 1
2.4K | R8 | R_0402_1005Metric | C25882 | 1
27 | R3,R4 | R_0402_1005Metric | C2909343 | 2
3.3u | L1 | L_0806_2016Metric | C42411119 | 1
33 | R12 | R_0402_1005Metric | C25105 | 1
4.7u | C18,C19,C20 | C_0402_1005Metric | C23733 | 3
5.1K | R1,R2 | R_0402_1005Metric | C25905 | 2
ABM8-272-T3 | Y1 | Crystal_SMD_3225-4Pin_3.2x2.5mm | C20625731 | 1
LED | D1 | LED_0603_1608Metric | C2286 | 1
LED | D2 | LED_0603_1608Metric | C2290 | 1
RP2350A | U1 | QFN-60-1EP_7x7mm_P0.4mm_EP3.4x3.4mm | C42411118 | 1
SS14 | D3,D4,D5 | D_SOD-123 | C49023418 | 3
TP4056-42-ESOP8 | U4 | SOIC-8-1EP_3.9x4.9mm_P1.27mm_EP2.41x3.3mm_ThermalVias | C16581 | 1
USB_C_Receptacle_USB2.0_14P | J1 | USB_C_Receptacle_HRO_TYPE-C-31-M-12 | C165948 | 1
W25Q128JVS | U3 | SOIC-8_5.3x5.3mm_P1.27mm | C97521 | 1
XC6206P332MR | U5 | SOT-23-3 | C5446 | 1
reset_flash | SW1 | SW_Push_SPST_NO_Alps_SKRK | C720477 | 1
DPAD_DOWN | SW5 | SW_PUSH_6mm+6mm_Dual |  | 1
BTN_B | SW7 | SW_PUSH_6mm+6mm_Dual |  | 1
BTN_A | SW6 | SW_PUSH_6mm+6mm_Dual |  | 1
BTN_X | SW10 | SW_PUSH_6mm+6mm_Dual |  | 1
DPAD_UP | SW2 | SW_PUSH_6mm+6mm_Dual |  | 1
DPAD_RIGHT | SW4 | SW_PUSH_6mm+6mm_Dual |  | 1
BTN_Y | SW13 | SW_PUSH_6mm+6mm_Dual |  | 1
DPAD_LEFT | SW3 | SW_PUSH_6mm+6mm_Dual |  | 1
MENU | SW8 | SW_PUSH_6mm+6mm_Dual |  | 1
Conn_01x08_Socket | J2 | 1.54_ TFT Header |  | 1
Conn_01x01 | J4 | TestPoint_Pad_2.0x2.0mm |  | 1
SW_SPDT | SW12 | SW_SLIDE-3pin_2.54_1.2mm-hole |  | 1
Conn_01x01 | J3 | TestPoint_Pad_2.0x2.0mm |  | 1
Conn_01x01 | J5 | TestPoint_Pad_2.0x2.0mm |  | 1
Conn_01x01 | J6 | TestPoint_Pad_2.0x2.0mm |  | 1

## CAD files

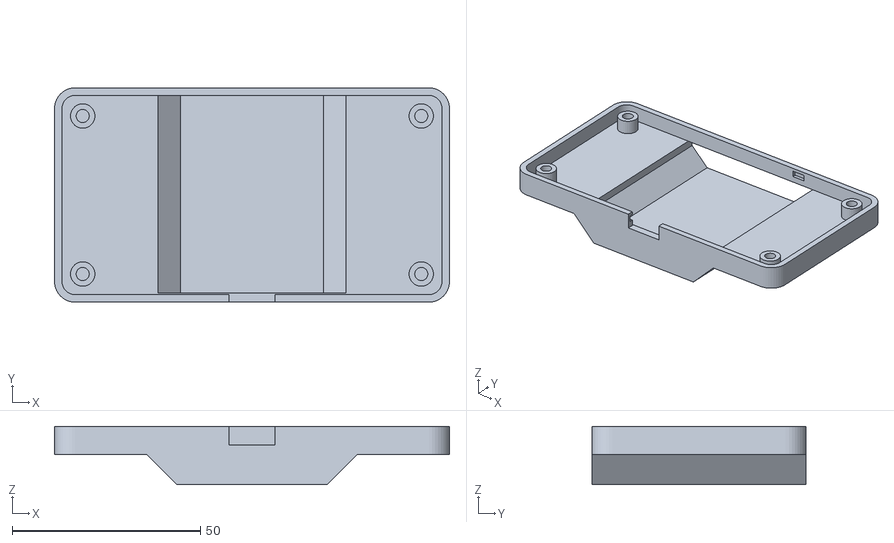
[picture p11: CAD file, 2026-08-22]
case/v2/3dp/BottomCasePart.stl
105.0 x 57.0 x 15.5

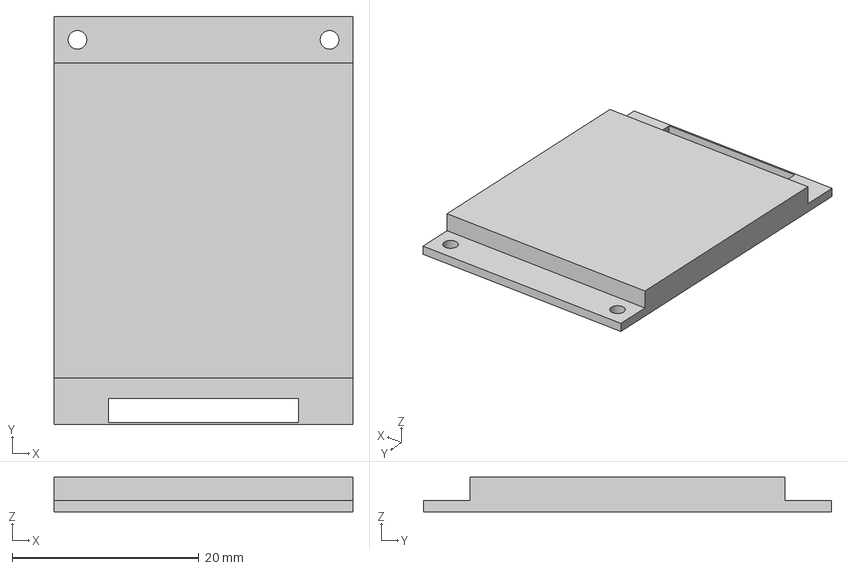
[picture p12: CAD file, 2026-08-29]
case/v2/st7789_display.step
32.0 x 43.7 x 3.70 mm

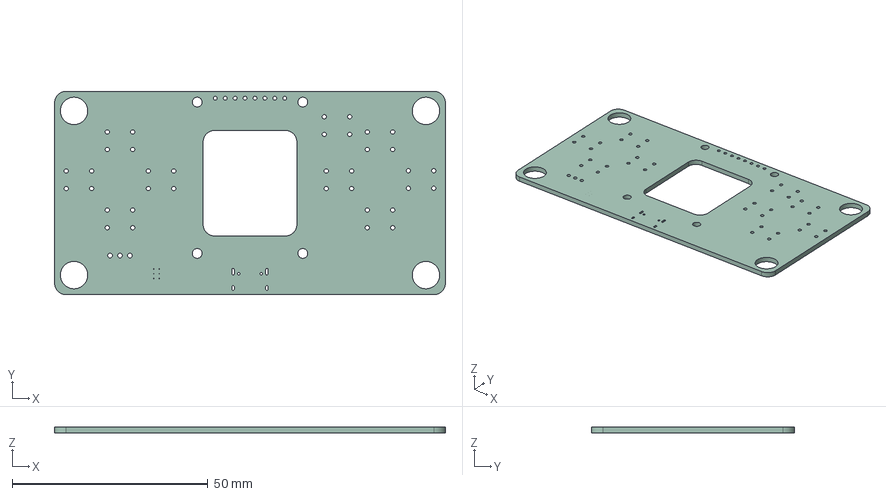
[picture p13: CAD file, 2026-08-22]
hardware-v2/pcba.step
100.0 x 52.0 x 1.51 mm

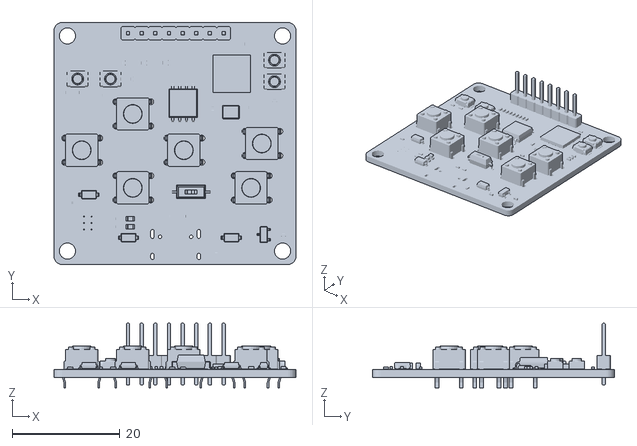
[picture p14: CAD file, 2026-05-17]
mini-games/pcba.stl
45.0 x 45.0 x 12.0

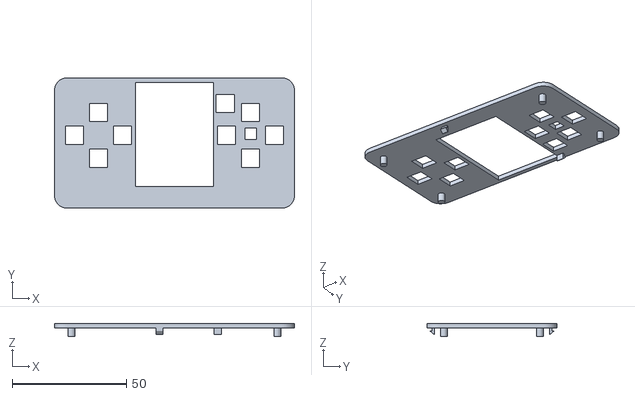
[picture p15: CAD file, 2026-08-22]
case/v2/3dp/TopCasePart.stl
105.0 x 57.0 x 5.90

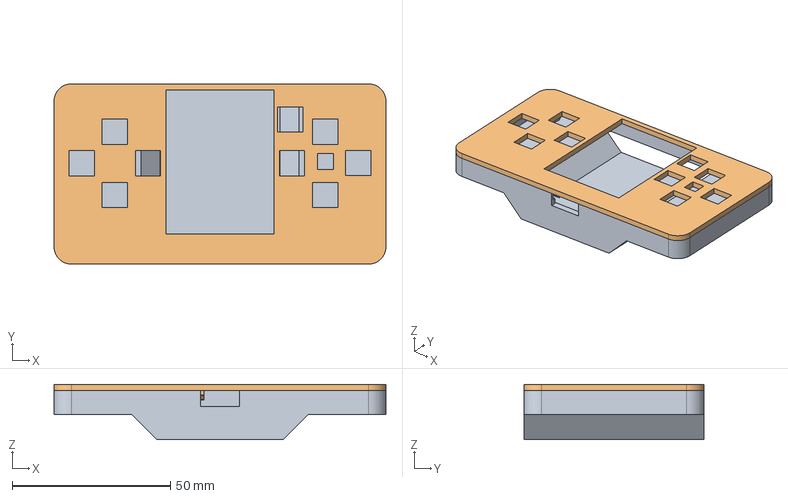
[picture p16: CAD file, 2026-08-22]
case/v2/casev2.step
105.0 x 57.0 x 17.5 mm
mini-games_PCB
BottomCasePart
TopCasePart

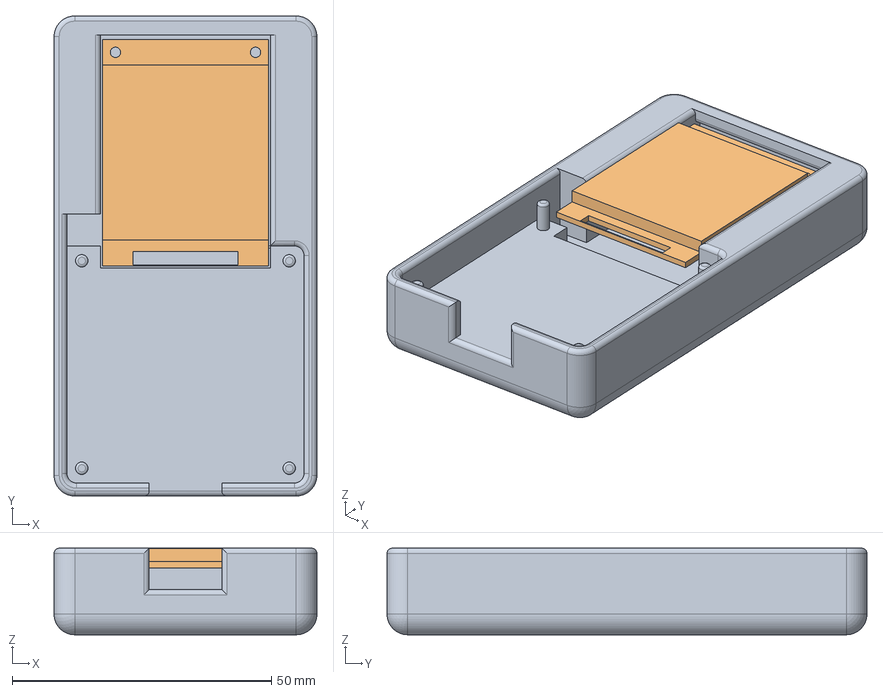
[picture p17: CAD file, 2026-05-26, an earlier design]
case/v1/Case.step
50.7 x 92.5 x 16.7 mm
Case_1
Screen

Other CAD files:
hardware-v2/.step
mini-games/.step
case/v1/case.3mf
case/v1/case.f3d
case/v1/case.stl
case/v2/casev2.f3d
case/v2/fbv2_including_pcb_and_screen.f3z
case/v2/st7789_display.f3d

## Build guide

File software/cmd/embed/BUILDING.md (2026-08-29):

# How the Ferretboard build system works

This document explains how MicroPython is embedded inside the Ferretboard Go
firmware and how the `cmd/embed` build turns that into two artefacts:

| Target | Command | Output | Purpose |
| --- | --- | --- | --- |
| host | `just host` | `spike` | PC reference: full REPL over stdin/stdout |
| device | `just device` | `ferret.uf2` | RP2040/RP2350 firmware (flash with picotool) |

Both share the same sources and differ only in the compiler/board support
files. The authoritative entry point is `justfile`; read it top to bottom with
this document.

---

## 1. The core idea

MicroPython's C interpreter is precompiled into a **static archive**
(`build/libmp_embed.a` on device, `build/libmp_embed_host.a` on the host). Go's
`main()` is the real entry point. The two sides meet through **cgo**:

* MicroPython C code that must reach the outside world calls Go functions that
  are `//export`ed (USB CDC, display, random, …).
* Go calls into MicroPython through `host.c`, which is compiled by cgo as part
  of the Go build.

```
+-------------------------------------------------------------+
| Go runtime (main.go, bridge.go, cdc_*.go, display_*.go)     |
|   main() -> ferret_boot() -> run_repl()                     |
+----------------------------|--------------------------------+
                             | cgo  (host.c: C glue)          |
+----------------------------v--------------------------------+
| libmicropython  (libmp_embed*.a, precompiled C)             |
|   py/*  shared/runtime/pyexec.c  shared/readline  extmod/*  |
+-------------------------------------------------------------+
```

---

## 2. Layout

```
cmd/embed/
  justfile             recipes: embed, mp-arm, mp-host, host, device, clean
  gen_cgo.sh           writes z_cgo_link_{host,tinygo}.go (include/link flags)
  host.c               C glue: ferret module trampolines, run_repl(), boot script
  bridge.go            //export funcs the `ferret` module calls (thin, engine-facing)
  flash_common.go      device flash driver (XO2 pico-flash library, SPI CS on GP22)
  flash_fs.go          //export ferret_* filesystem + image service (Go-owned LittleFS)
  cdc_stub.go          host CDC: reads stdin / writes stdout            [go:build !tinygo]
  cdc_tinygo.go        device CDC: TinyUSB ring buffer + pump goroutine  [go:build tinygo]
  display_stub.go      host display singleton (no-op)                   [go:build !tinygo]
  display_device.go    device display singleton (ST7789)                [go:build tinygo]
  main.go              Go entry point, MP GC heap, display singleton
  ferret_abi.h         hand-written C prototypes for the Go //export funcs
  port/
    mpconfigport.h     our MicroPython feature configuration
    mphalport.c        MP stdio/ticks hooks -> ferret_cdc_* (Go)
    mphalport.h        MP HAL extra declarations (interrupt_char prototype)
    repl_stubs.c       mp_import_stat + mp_lexer_new_from_file -> Go exports
    embed-genhdr.mk    regenerates qstrs / root pointers / module defs
  z_cgo_link_*.go      generated (see §5)
  build/               per-target .o files + the static archives (gitignored)
```

`MICROPYTHON_ROOT` must point at a full MicroPython **checkout** (not a vendored
copy): the build generates an embed package inside it and runs MicroPython's own
make rules. Set it as
`just --set MICROPYTHON_ROOT /path/to/micropython <recipe>`
(it defaults to `~/src/micropython`).

---

## 3. Stage 1: the embed package (recipe `embed`)

MicroPython ships a generator at
`examples/embedding/micropython_embed.mk` that emits a self-contained package
into `$MICROPYTHON_ROOT/examples/embedding/micropython_embed/`:

* `py/*` — the whole core interpreter, plus `genhdr/` (generated headers),
* `port/` — the stock embed port (`mpconfigport_common.h`, `embed_util.c`, …).

The `embed` recipe then **overlays our files** onto that package:

1. Our `port/mpconfigport.h`, `mphalport.c`, `mphalport.h`, `repl_stubs.c`
   replace the stock ones. `mpconfigport.h` is the master switch for every MP
   feature (compiler, GC, `sys`, `readline`, REPL helpers, banner). Notably it
   enables `MICROPY_ENABLE_EXTERNAL_IMPORT` so Python can `import` from files
   (see §9), disables VFS/`os`/`binascii`/`io` (the filesystem lives in Go
   instead — see `flash_fs.go`), and re-enables a minimal set of useful builtin
   modules above the `MICROPY_CONFIG_ROM_LEVEL_MINIMUM` defaults: `time`
   (sleep/ticks), `math` (+ float support via soft-float/picolibc), `struct`,
   `array` (with slice assign), `collections` (namedtuple/deque/OrderedDict)
   and slices.
2. Extra upstream sources are copied in because the stock generator ships only a
   minimal subset:
   * `shared/runtime/pyexec.{c,h}` — the REPL (friendly / raw / paste modes),
   * `shared/runtime/interrupt_char.{c,h}` — `mp_hal_set_interrupt_char` (Ctrl-C),
   * `shared/readline/` — line editing used by the friendly REPL.
   * `extmod/modtime.{c,h}` — the `time` module (`sleep`, `ticks_*`), backed by
     `mp_hal_delay_ms/us` + `mp_hal_ticks_us/cpu` in `mphalport.c`.
   (`extmod/vfs*`, `modos.c`, `modbinascii.c` and `port/flash_storage.c` were
   used by the pre-Go-FS layout and must **not** be copied in any more.)
3. **`embed-genhdr.mk` regenerates the package's `genhdr/`.** This is the
   subtle bit — see §4.
4. `gen_cgo.sh` writes the cgo include/link flags (see §5).

---

## 4. Why `genhdr/` must be regenerated

MicroPython scans its **compiled sources** to build three generated headers:

* `qstrdefs.generated.h` — every `MP_QSTR_*` used in C,
* `root_pointers.h` — every `MP_REGISTER_ROOT_POINTER` (state that the GC must
  trace, e.g. readline history),
* `moduledefs.h` — every `MP_REGISTER_MODULE` (e.g. `sys`).

The stock embed generator only scans `py/` sources, so the extra files copied
in step 2 would contribute nothing: you would get link errors like
`undefined reference to MP_QSTR_mount` and `import ferret`'s helpers would
misfire. `embed-genhdr.mk` therefore re-runs MicroPython's
own generation machinery *inside the package directory*, adding our sources to
`SRC_QSTR`:

```make
include $(MICROPYTHON_TOP)/py/py.mk
SRC_QSTR += $(wildcard extmod/*.c) $(wildcard shared/runtime/*.c) shared/readline/readline.c
include $(MICROPYTHON_TOP)/py/mkrules.mk
```

Two gotchas, both hit during bring-up:

* **`SRC_QSTR +=` must precede `include mkrules.mk`.** GNU make expands rule
  prerequisites immediately, so the `qstr.i.last` rule captures `SRC_QSTR` at
  parse time — adding files after the include has no effect.
* **The make must run with the package directory as CWD** (the justfile does
  `cd $EMBED_DIR`), because `$(wildcard extmod/*.c)` and the `-I.` include paths
  are relative. Also add `vpath mpconfigport.h port` so the qstr dependency
  scan can find our config file.
* **The generated headers are stale after a config change.** The per-file
  `qstr.i` scan bakes in `mpconfigport.h` as it was when the package was
  generated. After editing MP features, `just embed` deletes
  `build-local/genhdr/` and `genhdr/` and regenerates from scratch — otherwise
  module/qstr lists from the old config leak into the build.

The regenerated headers land in `build-local/genhdr/` and are copied back over
the package's `genhdr/`.

---

## 5. Stage 2: compiling the archive (recipes `mp-arm` / `mp-host`)

`mp-arm` and `mp-host` are the same recipe with a different compiler:

```sh
find $EMBED_DIR -name '*.c' | while read src; do
    <gcc | arm-none-eabi-gcc> -I$ROOT -I$EMBED_DIR ... -c "$src"
done
ar rcs build/libmp_embed*.a build/{arm,host}/*.o
```

* `-I$ROOT` lets sources find `ferret_abi.h`.
* The device uses `-mcpu=cortex-m0plus` (RP2040) or `-mcpu=cortex-m33`
  (RP2350), chosen by `TARGET` (`pico` / `pico2`).
* Sources are compiled with `-fno-common`; the archive is then handed to the Go
  link step through cgo.

---

## 6. Stage 3: cgo glue (`gen_cgo.sh`, `host.c`, `z_cgo_link_*.go`)

`host.c` is compiled by cgo (it is a normal file in the Go package) and needs
the MicroPython include paths. Those absolute paths depend on
`MICROPYTHON_ROOT`, so `gen_cgo.sh` bakes them into two generated files:

* `z_cgo_link_host.go` (`//go:build !tinygo`) —
  `#cgo LDFLAGS: -Lbuild -lmp_embed_host -lm`,
* `z_cgo_link_tinygo.go` (`//go:build tinygo`) —
  `#cgo LDFLAGS: -Lbuild -lmp_embed`.

These are generated (`DO NOT EDIT`) and gitignored.

`host.c` is the bridge in both directions:

* **Go -> MicroPython:** `ferret_boot()` captures the GC heap; `run_repl()`
  boots MP and runs its REPL forever. `register_ferret_module()` builds the
  `ferret` module at runtime (see §8).
* **MicroPython -> Go:** each `ferret.*` function is a small C trampoline
  (`t_fill`, `t_fill_rect`, …) that unpacks MP arguments and calls the matching
  `//export` Go function (`ferret_fill`, … in `bridge.go`).

The C prototypes for those Go functions are hand-written in `ferret_abi.h`
rather than pulled from cgo's generated header, so `mphalport.c` (compiled into
the archive *outside* cgo) can include them too. Keep the signatures in sync
with `bridge.go` and `cdc_*.go`.

---

## 7. Stage 4: the final link

* **Host:** `go build -o spike .` — the Go linker calls cgo, which links
  `host.c` + `libmp_embed_host.a`. `display_stub.go` and `cdc_stub.go` (build
  tag `!tinygo`) stand in for hardware, so the reference runs anywhere.
* **Device:** `tinygo build -target pico -o ferret.uf2 .` — TinyGo compiles the
  Go engine, links the same archive, and packages a UF2. `display_device.go`
  and `cdc_tinygo.go` (build tag `tinygo`) provide the real display and USB.

`tinygo` must be on `PATH` (e.g. `/tmp/opencode/tinygo/bin`); the justfile does
not bundle it.

---

## 8. The `ferret` module and the qstr boundary

MicroPython interns every identifier at build time into an enum
(`MP_QSTR_*`). Our Go engine is **not** scanned by that generator, so
`MP_QSTR_ferret` does not exist in C. Instead the module is assembled at
runtime:

```c
void register_ferret_module(void) {
    mp_obj_t mod = mp_obj_new_module(qstr_from_str("ferret"));
    mp_obj_dict_store(mp_obj_module_get_globals(mod),
        MP_OBJ_NEW_QSTR(qstr_from_str("fill")), MP_OBJ_FROM_PTR(&t_fill_obj));
    ...
}
```

`qstr_from_str` interns on the fly, so any string works. A soft reset (Ctrl-D)
clears MP's module registry, so `mpconfigport.h` also defines
`MICROPY_BOARD_BEFORE_PYTHON_EXEC(...) register_ferret_module()`, which pyexec
calls before *every* paste/exec. Re-registration is idempotent.

---

## 9. Runtime flow

1. `main()` creates the display singleton, then calls `ferret_boot(heap, size)`
   (stores the GC heap for soft-reset re-init) and `run_repl()`.
2. `run_repl()` anchors MP's stack scanner at its own frame
   (`mp_stack_set_top`), calls `mp_embed_init` (`gc_init` + `mp_init`) and
   `register_ferret_module()`, then loops:
   * `pyexec_friendly_repl()` — `>>> ` line editing, paste mode (Ctrl-E),
     raw mode (Ctrl-A), soft reset (Ctrl-D on an empty line),
   * `pyexec_raw_repl()` — the `OK`/`\x04\x04` framing the editor's raw-REPL
     tools use.
3. **stdio routing:** MP's `mp_hal_stdin_rx_chr` / `mp_hal_stdout_tx_strn`
   (in `mphalport.c`) call `ferret_cdc_read` / `ferret_cdc_write`.
   * Device: `cdc_tinygo.go` — `pumpCDC()` fills a ring buffer from TinyUSB;
     `ferret_cdc_read()` blocks (spin + `runtime.Gosched()`) because pyexec
     expects blocking reads; writes go straight to `machine.Serial`.
   * Host: `cdc_stub.go` bridges to `os.Stdin` / `os.Stdout`.
4. **the filesystem is Go-owned.** `flash_fs.go` mounts a LittleFS volume on
   the flash driver (`flash_common.go`) at boot and serves the `ferret.*` file
   and image functions. MicroPython never touches storage directly: with
   `MICROPY_ENABLE_EXTERNAL_IMPORT` set and VFS disabled, `mp_import_stat()` /
   `mp_lexer_new_from_file()` (in `repl_stubs.c`) route every `import` through
   the Go exports `ferret_stat` / `ferret_read_file`. A 16 KB scratch buffer
   (`ferret_fs_buf`, shared between boot script and module imports) is safe
   because source text is only needed until compilation finishes.
5. **the boot script:** `run_boot_script()` (in `host.c`) runs after every
   (re)init: it fetches `/main.py` from Go and executes it with a **fresh
   module globals dict**, so a game boots automatically on power-up and on
   Ctrl-D, with its own namespace and working `import`s. Exceptions are caught
   with `nlr_push` and printed as a traceback — the REPL survives a crashing
   boot script.
6. **soft reset (Ctrl-D):** pyexec returns `PYEXEC_FORCED_EXIT`; `run_repl`
   runs `mp_deinit()` → `gc_sweep_all()` → `mp_embed_init(...)` (fresh heap +
   VM state) and continues the loop — which re-runs the boot script. `ferret`
   is re-registered on the next exec via the board hook.

---

## 10. Pitfalls discovered during bring-up

1. **Stack top must be a C-frame address.** On the host, cgo runs C on a
   dedicated OS thread; if `mp_stack_set_top` used a Go goroutine address, GC's
   stack scan walked gigabytes of unmapped memory and segfaulted. Anchoring it
   at `run_repl()`'s own frame is correct because all MP activity stays within
   that one cgo call.
2. **`mp_init()` must happen before `register_ferret_module()`** — registering
   against an uninitialised VM hangs. Both now live inside `run_repl()`.
3. **No POSIX on bare metal.** `MICROPY_READER_POSIX` pulls in `open/read/close/
   errno`, which TinyGo's libc lacks. `pyexec.c` references
   `mp_lexer_new_from_file` for the never-used "run file by path" path, so
   `repl_stubs.c` implements it (plus `mp_import_stat`) via the Go FS instead.
4. **`mp_hal_ticks_ms` / `mp_hal_stdout_tx_str` are port responsibilities.**
   pyexec needs them; `mphalport.c` implements both (hardware timer on device,
   `clock_gettime` on host).
5. **genhdr scan coverage** — see §4. If a new module/source adds qstrs or root
   pointers and isn't in `SRC_QSTR`, the *link* fails with `undefined reference`
   to `MP_QSTR_*`, not the compile. Stale generated headers after a config
   change are just as sneaky — see §4.
6. **`MP_STATE_PORT`** must alias `MP_STATE_VM` or readline history doesn't
   compile.
7. **tinygo is not bundled** — `just device` needs it on `PATH`.
8. **Boot scripts need explicit globals.** The REPL only creates its globals
   dict on first input, and `mp_parse_compile_execute(lex, kind, globals,
   locals)` overwrites the thread globals with its arguments — passing `NULL`
   makes `mp_compile` capture a NULL module context, which segfaults on the
   first name lookup. Pass a fresh `mp_obj_new_dict()`.
9. **Exceptions must not cross the cgo boundary.** nlr-longjmp across Go frames
   is undefined behaviour (the host build hangs, the device crashes). Any code
   that runs Python from C — like the boot script — must `nlr_push`/catch and
   print the traceback.
10. **tinyfs/littlefs quirks.** `File.Write`/`Read` panic on empty buffers
    (guard `len == 0`); `Mkdir` on an existing directory reports an "already
    exists" error that must be tolerated on remount; error checks compare
    against `littlefs.Error(-2)` / `Error(-17)` (there is no `ErrNoEntry`).
11. **Base64 uploads stream.** The editor may split payloads at arbitrary
    chunk boundaries, so `flash_fs.go` retains up to three leftover characters,
    decodes complete quartets into a fixed buffer, and writes them directly to
    a temporary LittleFS file. `write_image_end` validates the final lengths and
    atomically renames that file over the published image.

---

## 11. Common tasks

**Add a `ferret` SDK function.** 1) add a Go method to
`internal/platform.Screen` if needed; 2) implement the `//export` func in
`bridge.go`; 3) declare it in `ferret_abi.h`; 4) add a trampoline +
`MP_DEFINE_CONST_FUN_OBJ_*` in `host.c` and store it in
`register_ferret_module()`.

**Enable an MP feature/module.** Add the `MICROPY_*` define to
`port/mpconfigport.h`. If it compiles extra sources (e.g. `extmod/foo.c`), copy
them into the package in the `embed` recipe **and** make sure they reach
`SRC_QSTR` in `embed-genhdr.mk`, then rebuild `embed` so `genhdr/` regenerates
(see the stale-genhdr gotcha in §4).

**Change the filesystem.** The volume, limits (`maxFsFile`, `maxImageFile`,
`imgCacheBudget`) and the `ferret.*` file/image API all live in `flash_fs.go`
and `ferret_abi.h`; nothing on the MicroPython side needs rebuilding. Note the
editor protocol: `write_file`/`append_file` for code, `write_image`/
`append_image`/`write_image_end` for base64 images, `image_manifest` to list
them, `delete_image` to remove one, and a soft reset to boot `/main.py`.

**Upgrade the MicroPython checkout.** Point `MICROPYTHON_ROOT` at the new
checkout and run `just embed` — the package and generated files are rebuilt
from scratch. Re-check §4/§10 items if upstream moved a generated-header rule or
changed a HAL prototype.

**Clean everything:** `just clean` removes `build/`, `spike`, `ferret.uf2` and
the generated cgo link files.

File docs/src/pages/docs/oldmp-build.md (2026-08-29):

---
layout: '../../layouts/DocsLayout.astro'
title: 'Building the old micropython system'
draft: false
category: "ogmp"
---

These are instructions for building the legacy micropython games system. There's really no reason for you to use it - its kind of buggy, and just bad compared to the new one. 

The current deployed editor is no longer compatible with this old system. You can find the old editor deployment here: [https://editor-puhp0agjy-louisbs-projects.vercel.app?_vercel_share=TvlfneAJnYLfwqdn5NOvuiplwbXqOOF9](https://editor-puhp0agjy-louisbs-projects.vercel.app?_vercel_share=TvlfneAJnYLfwqdn5NOvuiplwbXqOOF9). This deployment is pinned to a commit before the editor changes happened. Alternatively, you can roll back to git commit **5ab1194** on the main branch and serve the Sveltekit server locally.

# Building instructions:
## Setup - what you need installed on your computer (macOS, likely very similar on linux, if you're on windows use WSL)
If you're on linux, all you'll need to change is to install the packages below with your distro's package manager

```zsh
brew install --cask gcc-arm-embedded
brew install cmake ninja
```

next, clone the micropython git repository and compile some things

```zsh
git clone https://github.com/micropython/micropython.git
cd micropython
make -C mpy-cross

cd ports/rp2
make submodules
```

Note: once you're at this stage, you can use the script ```build.sh``` in this repository to build it. Note, you will have to adapt this script to where everything is on your machine, so its probably easier to just do the commands manually.

## Building
Hop into the ```ports/rp2``` directory inside your micropython git clone.

```zsh
# delete old build cache
rm -rf build-ferretboard

#run the build command with paths to the board directory and the manifest.py. For me this is
make BOARD_DIR=/Users/louisb/Documents/hardware/macondo-games/mp-sdk/boards/ferretboard FROZEN_MANIFEST=/Users/louisb/Documents/hardware/macondo-games/mp-sdk/boards/ferretboard/manifest.py

```

This will output a uf2 file in the ```ports/rp2/build-ferretboard/``` directory inside the micropython repo, which you can then copy onto the device. If you're using the script as i am, it will instead copy it directly into this repository.

# Licences
This software itself is AGPL licenced. 

Acknowledgement is also given to the framebuf2 library, which makes up an integral part of this repository. This component is licenced under a MIT licence.

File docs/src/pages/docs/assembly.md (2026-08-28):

---
layout: '../../layouts/DocsLayout.astro'
title: 'Assembly (v1)'
draft: false
category: "general"
---

## Assembly instructions
These instructions are for version one of the hardware. Version two has a different pcb and a two-part case, and is still in development.

To assemble the device, start by 3d printing the shell, which can be found at ```/case/v1/case.stl``` in this repository. I would reccomend doing this with some kind of high precision setting on your printer - my first print used the Draft quality with layer height of 0.2mm, but my second used 0.08mm and it looked a lot better. I just printed this on my school's Bambu Lab P1S printer. Here's how it looks, printed in white on this 0.08mm setting.
The case, printed in white

Next, you'll need to solder the buttons to the PCB that you've got printed and assembled. Get 6 generic 6x6x5mm push-to-make switches, and solder them into the holes on the pcb. Get a 3.7v LiPo battery (the finished build uses 1000mAh), and solder the positive and negative lines to the copper pads of the board as indicated below. Be very careful about polarity and do not work on, cut, or solder battery wires in a way that can short them together:
Where to solder things

Key: Battery as indicated, positive to J4, negative to J3. Make sure these lines do not touch.
Switches: solder legs to the through-hole pads for SW2-SW7, as highlighted in yellow.

Next, get your screen and solder it to the screen connector at the top of the PCB. The leftmost pin, from the front of the board, is the BL pin, with GND on the far right. This means that I had to mount the specific display I bought from aliexpress upside down, and flip all the coordinates in software.
Connecting the screen

Once you've done that, the device is pretty much ready to go. Slot the whole contraption into the 3d printed case - the case is designed so that the battery goes behind the screen and then the wires for the battery come down and snake through the little notch to the left of the battery compartment. There are four posts on the lower section of the case, which you can use to hold the PCB in place through the circular holes on each corner of the PCB.

If you leave it like that, it will work, but depending on the sizes of all your components, everything will probably rattle and tilt and slide around a ton. I solved this problem by liberally applying small bits of furniture skates, double sided tape, and foam to hold everything in place. This is something that I can probably improve on in version two of the system.

From there, all you'll need to do is to load the code onto the thing. For the current MicroPython SDK and web editor, build the firmware using the [current MicroPython building guide](/docs/micropython-building). Hold the board's flash/BOOTSEL button while plugging it into your computer over USB C, then copy the compiled ```ferret.uf2``` file onto the drive that appears. You can also flash it from a terminal with ```picotool load ferret.uf2 -f```. The board will reboot when it has finished.

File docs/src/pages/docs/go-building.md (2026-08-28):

---
layout: '../../layouts/DocsLayout.astro'
title: 'Building the Go system'
draft: false
category: "go"
---

This page is for the standalone Go games system. If you want to use the current MicroPython SDK and web editor, follow the [MicroPython building guide](/docs/micropython-building) instead.

### Wasm (golang system on web)
You'll need to compile the binary for wasm using tinygo. I'm on a mac, so keep in mind that all these commands are macos specific and may be different for you. For me, tinygo is installed through Homebrew.

Run these commands from the ```/software``` directory:

```sh
GOOS=js GOARCH=wasm tinygo build -o ./web/main.wasm -target wasm -tags=wasm ./cmd/wasm
cp "$(tinygo env TINYGOROOT)/targets/wasm_exec.js" ./web/
```

It can be quicker to use the typical Go WASM handler for builds, since the tinygo toolchain can take quite a while, even on a decent computer. In this case, the js file is different, so the commands are:

```sh
cp "$(go env GOROOT)/lib/wasm/wasm_exec.js" ./web/
GOOS=js GOARCH=wasm go build -o ./web/main.wasm ./cmd/wasm
```

Then, regardless of which you use, you need to actually serve this directory. For debugging, I do this through cd'ing into it and then running ```python3 -m http.server```, which works well enough for me.

If you're building the version used by the Astro frontend, run these commands from ```/software```:

```sh
cp "$(go env GOROOT)/lib/wasm/wasm_exec.js" ../docs/public/
GOOS=js GOARCH=wasm go build -o ../docs/public/main.wasm ./cmd/wasm
```

### Building (golang system on device)
To compile the standalone Go games firmware for the version one RP2040 device, you'll need tinygo installed on your computer. Then, cd into the ```/software``` folder and run this command:

```sh
tinygo build -target=pico -o ./out/firmware.uf2 ./cmd/device
```

This will create a .uf2 build artifact in the ```/software/out``` directory. Alternatively, I have chosen not to include this in my .gitignore, so you can find a prebuilt file in this repository at that location, although i make no guarantees about it being up to date.

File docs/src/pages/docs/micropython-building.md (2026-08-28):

---
layout: '../../layouts/DocsLayout.astro'
title: 'Building the current MicroPython SDK'
draft: false
category: "mp"
---

The current MicroPython firmware is built from ```/software/cmd/embed```. This is the version used by the web editor, not the older firmware under ```/mp-sdk```.

## Setup

You will need:

- Go
- TinyGo
- just
- make
- gcc and binutils for a host build
- the Arm GNU toolchain (```arm-none-eabi-gcc``` and ```arm-none-eabi-ar```) for a device build
- a full clone of MicroPython

On macOS, most of these can be installed with Homebrew. The package names may be different on Linux.

```sh
xcode-select --install
brew install go tinygo just
brew install --cask gcc-arm-embedded
```

Clone MicroPython somewhere outside this repository:

```sh
git clone https://github.com/micropython/micropython.git ~/src/micropython
```

The build uses ```~/src/micropython``` by default. If you put it somewhere else, set ```MICROPYTHON_ROOT``` when running the commands below.

## Building for the device

From the embedded firmware directory, run:

```sh
cd software/cmd/embed
just device
```

If your MicroPython checkout is somewhere else:

```sh
cd software/cmd/embed
MICROPYTHON_ROOT=/path/to/micropython just device
```

This produces ```software/cmd/embed/ferret.uf2```. The default target is version one, using the RP2040 and 16MB flash configuration in ```ferretboard.json```.

To build the version two RP2350 target instead, use:

```sh
just --set TARGET ferretboard2.json device
```

You can copy the UF2 onto the board while it is in BOOTSEL mode, or flash it with picotool:

```sh
picotool load ferret.uf2 -f
```

## Building the host reference

There is also a host build with a MicroPython REPL over your normal terminal. Drawing is stubbed out, but it is useful for checking that the interpreter and ```ferret``` module build correctly.

```sh
cd software/cmd/embed
just host
./spike
```

The host build creates ```spike``` in the same directory. Its fake flash filesystem is stored in ```build/ferret.img``` by default.

## Cleaning

To remove the generated archives and executables:

```sh
cd software/cmd/embed
just clean
```

For a much more detailed explanation of how all the C, Go and MicroPython parts are compiled and linked together, see ```/software/cmd/embed/BUILDING.md``` in the repository.

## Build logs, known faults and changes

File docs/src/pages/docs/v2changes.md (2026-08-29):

---
layout: '../../layouts/DocsLayout.astro'
title: 'Changes for V2'
draft: false
category: "general"
---

The v2 of this hardware is significantly different to version one. Here is a description of what these differences are, why they are, and what this changes for the device

## Change from rp2040 to rp2350
This is the main change that motivated the redesign in the first place. The rp2040 has only 264KB of SRAM, which is fine, but we are starting to outgrow it. This limits us in quite a few ways, including limiting us to a single buffer rather than a double buffer. It also runs the risk of OOM errors, especially when we're dealing with the embedded micropython system - this introduces the overhead of both micropython and go. So far, this is ok, but struggling, on the rp2040 - there have been some OOM problems with uploading images to the device and displaying them from the editor. The rp2350 upgrades to 520KB of internal ram, which gives us room for

- a double buffer (230kb)
- a cache for recently used sprites, which includes a full screen background and some smaller sprites. the full screen background here will be another 115kb of image, and then a budget of perhaps 64kb or so for sprites. That sums up to 179KB there.

After this image caching, we get 110KB of headroom for the Go process, micropython, and everything else. I think that should be enough - it is still cutting it a bit fine, but should be good.

Apart from the RAM, the RP2350 also gives us more processing power. The RP2040 uses a dual core ARM CORTEX M0+ at 133MHz - the 2350 has dual core CORTEX M33 at 150MHz. This improves speeds by at least double based on a lot of stuff I could find online. Also, the 2350 has a designated FPU, so the maths simulations that struggled so much on the 2040 might actually run.

## New Form Factor
I still really like the form factor of the original. That being said, its not very ergonomic, and is kind of cramped to have both thumbs in the tiny space that it has. V2 changes this to a more traditional setup with d-pad on the left, the screen in the middle, and ABXY on the right. This should feel better to hold.

The basic buttons on v1 are also replaced with softer touch buttons that feel more like a games controller on v2 (they feel VERY similar to the pushing force required on my Dualsense controller). Will be nice.

## Minor things and general polish
A few things here - the case is better designed to fit around it, and i think will look really nice. There's also a few things fixed - the reset button on v1 didn't work, meaning that to reset the thing at the moment i have to manually short QSPI_SS to ground with tweezers while rebooting it. This is obviously not ideal.

Rotation was annoying on v1 - the st7789 chip in the display is meant for a 320x240 display, and try as i might i couldnt get the rotation parameters to work on it; thus, i had to do software rotation for EVERYTHING. I haven't benchmarked it, but i imagine this isnt great for performance. The display is mounted the right way up, not upside down, in v2, so the native coordinates work without rotation.

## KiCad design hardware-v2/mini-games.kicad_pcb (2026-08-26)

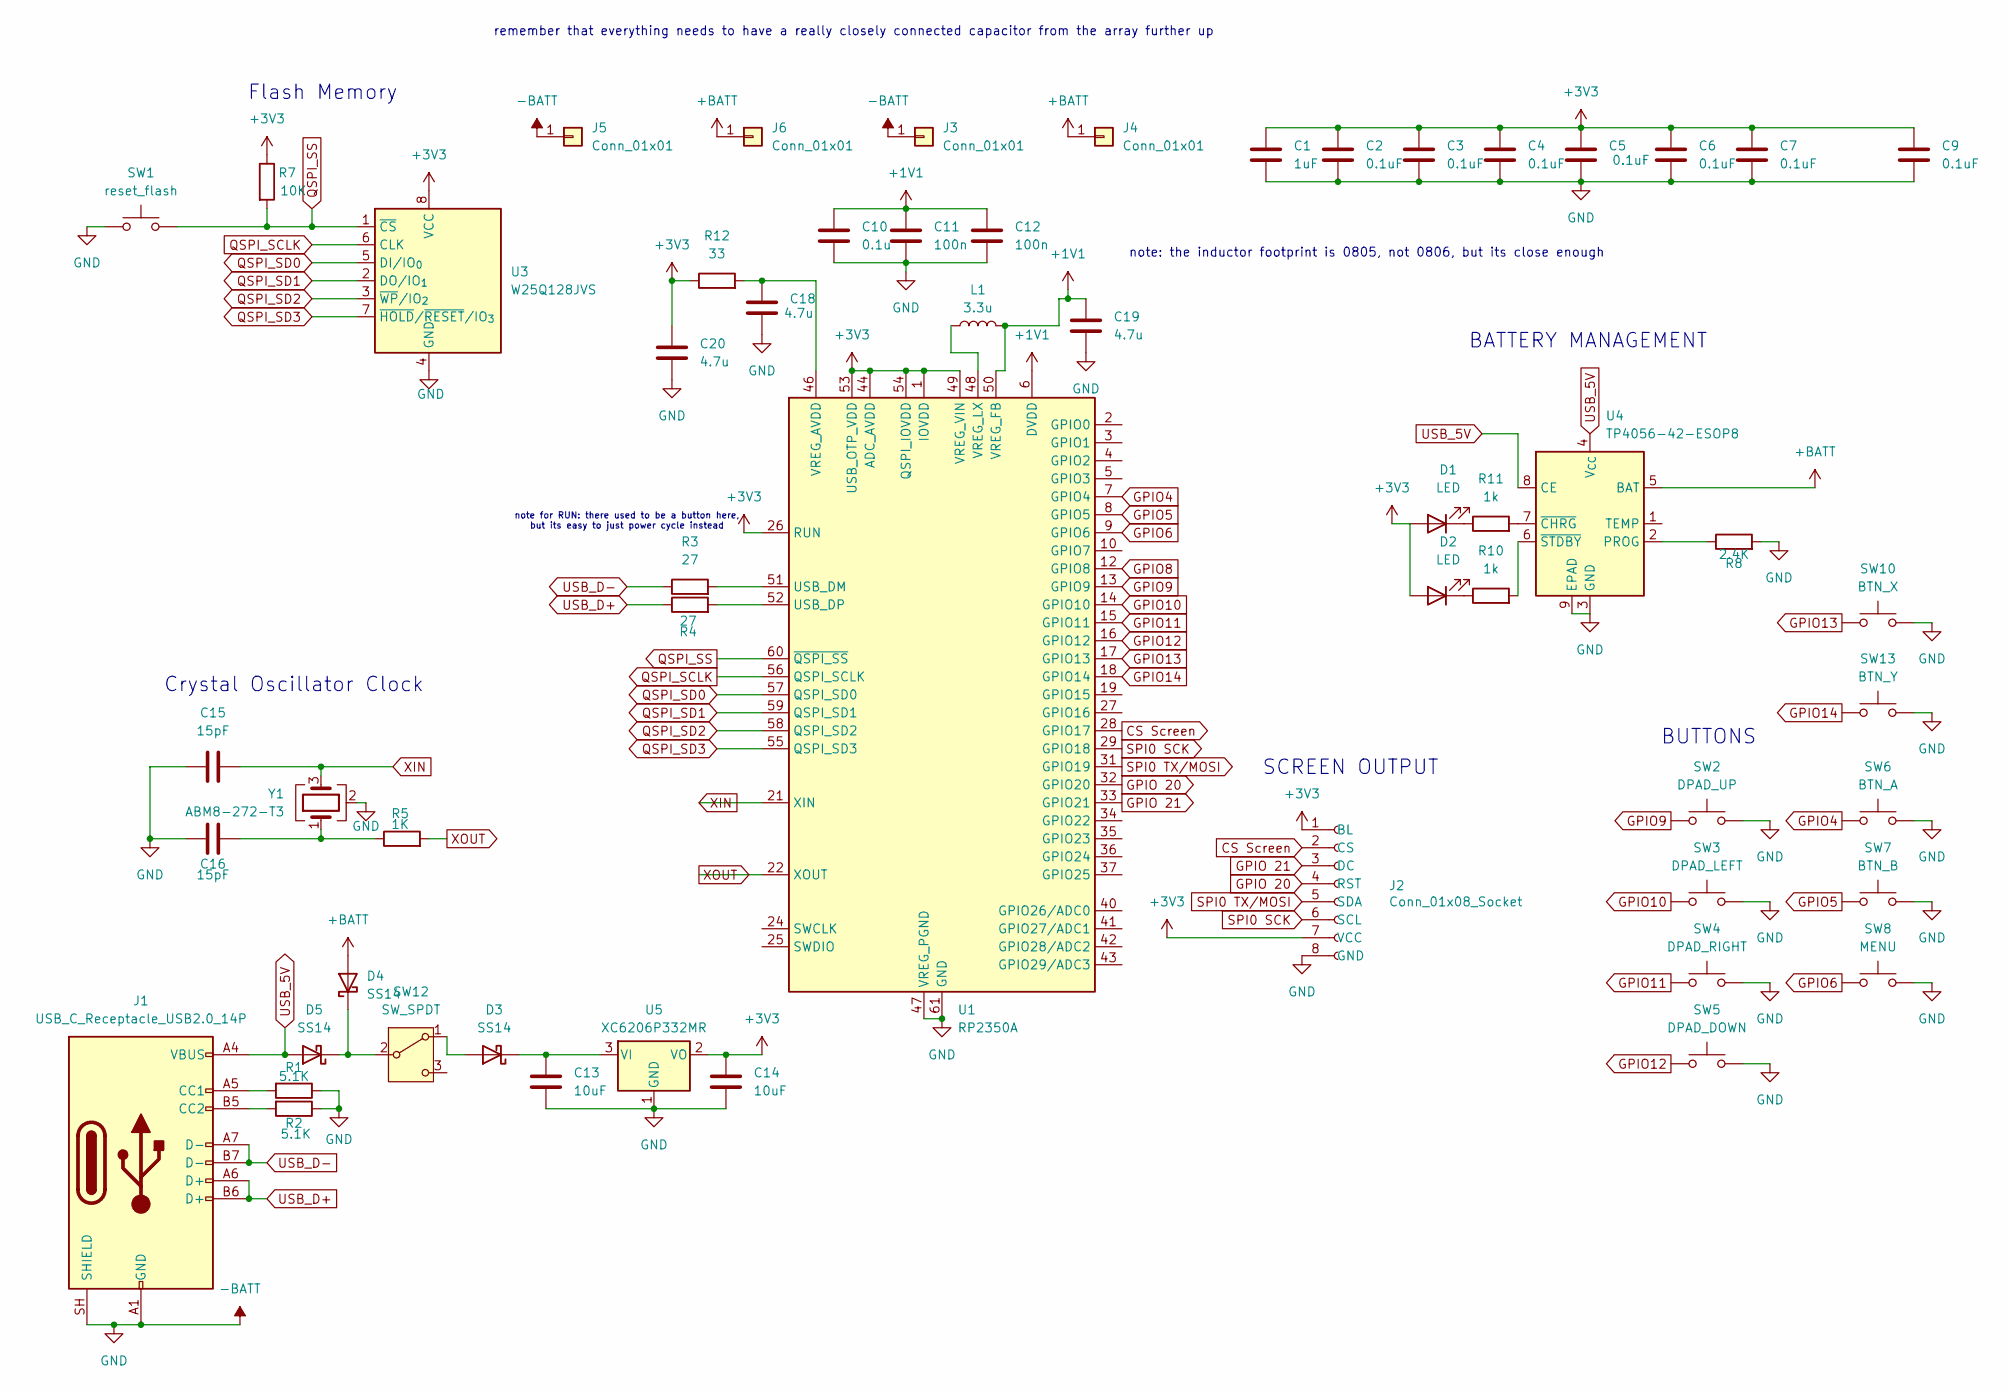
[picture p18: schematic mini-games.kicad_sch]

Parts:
C1: 1uF; C_0402_1005Metric
C2, C3, C4, C5, C6, C7, C9: 0.1uF; C_0402_1005Metric
C10: 0.1u; C_0402_1005Metric
C11, C12: 100n; C_0402_1005Metric
C13, C14: 10uF; C_0402_1005Metric
C15, C16: 15pF; C_0402_1005Metric
C18, C19, C20: 4.7u; C_0402_1005Metric
D1, D2: LED; LED_0603_1608Metric
D3, D4, D5: SS14; D_SOD-123
J1: USB_C_Receptacle_USB2.0_14P; USB_C_Receptacle_HRO_TYPE-C-31-M-12
J2: Conn_01x08_Socket; 1.54_ TFT Header
J3, J4, J5, J6: Conn_01x01; TestPoint_Pad_2.0x2.0mm
L1: 3.3u; L_0806_2016Metric
R1, R2: 5.1K; R_0402_1005Metric
R3, R4: 27; R_0402_1005Metric
R5: 1K; R_0402_1005Metric
R7: 10K; R_0402_1005Metric
R8: 2.4K; R_0402_1005Metric
R10, R11: 1k; R_0402_1005Metric
R12: 33; R_0402_1005Metric
SW1: reset_flash; SW_Push_SPST_NO_Alps_SKRK
SW2: DPAD_UP; SW_PUSH_6mm+6mm_Dual
SW3: DPAD_LEFT; SW_PUSH_6mm+6mm_Dual
SW4: DPAD_RIGHT; SW_PUSH_6mm+6mm_Dual
SW5: DPAD_DOWN; SW_PUSH_6mm+6mm_Dual
SW6: BTN_A; SW_PUSH_6mm+6mm_Dual
SW7: BTN_B; SW_PUSH_6mm+6mm_Dual
SW8: MENU; SW_PUSH_6mm+6mm_Dual
SW10: BTN_X; SW_PUSH_6mm+6mm_Dual
SW12: SW_SPDT; SW_SLIDE-3pin_2.54_1.2mm-hole
SW13: BTN_Y; SW_PUSH_6mm+6mm_Dual
U1: RP2350A; QFN-60-1EP_7x7mm_P0.4mm_EP3.4x3.4mm
U3: W25Q128JVS; SOIC-8_5.3x5.3mm_P1.27mm
U4: TP4056-42-ESOP8; SOIC-8-1EP_3.9x4.9mm_P1.27mm_EP2.41x3.3mm_ThermalVias
U5: XC6206P332MR; SOT-23-3
Y1: ABM8-272-T3; Crystal_SMD_3225-4Pin_3.2x2.5mm

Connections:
+1V1: C10.1, C11.1, C12.1, C19.1, L1.2, U1.6 (DVDD), U1.23 (DVDD), U1.39 (DVDD), U1.50 (VREG_FB)
+3V3: C1.1, C2.1, C3.1, C4.1, C5.1, C6.1, C7.1, C9.1, C14.1, C20.1, D1.2 (A), D2.2 (A), J2.1 (BL), J2.7 (VCC), R7.1, R12.1, U1.1 (IOVDD), U1.11 (IOVDD), U1.20 (IOVDD), U1.26 (RUN), U1.30 (IOVDD), U1.38 (IOVDD), U1.44 (ADC_AVDD), U1.45 (IOVDD), U1.49 (VREG_VIN), U1.53 (USB_OTP_VDD), U1.54 (QSPI_IOVDD), U3.8 (VCC), U5.2 (VO)
+BATT: D4.2 (A), J4.1 (Pin_1_1), J6.1 (Pin_1_1), U4.5 (BAT)
-BATT: C1.2, C2.2, C3.2, C4.2, C5.2, C6.2, C7.2, C9.2, C10.2, C11.2, C12.2, C13.2, C14.2, C15.1, C16.1, C18.2, C19.2, C20.2, J1.A1 (GND), J1.A12 (GND), J1.B1 (GND), J1.B12 (GND), J1.SH (SHIELD), J2.8 (GND), J3.1 (Pin_1_1), J5.1 (Pin_1_1), R1.1, R2.1, R8.2, SW1.1, SW2.2, SW3.2, SW4.2, SW5.2, SW6.2, SW7.2, SW8.2, SW10.2, SW13.2, U1.47 (VREG_PGND), U1.61 (GND), U3.4 (GND), U4.3 (GND), U4.9 (EPAD), U5.1 (GND), Y1.2 (G), Y1.4 (G)
CS Screen: J2.2 (CS), U1.28 (GPIO17)
GPIO4: SW6.1, U1.7 (GPIO4)
GPIO5: SW7.1, U1.8 (GPIO5)
GPIO6: SW8.1, U1.9 (GPIO6)
GPIO8: U1.12 (GPIO8)
GPIO9: SW2.1, U1.13 (GPIO9)
GPIO10: SW3.1, U1.14 (GPIO10)
GPIO11: SW4.1, U1.15 (GPIO11)
GPIO12: SW5.1, U1.16 (GPIO12)
GPIO13: SW10.1, U1.17 (GPIO13)
GPIO14: SW13.1, U1.18 (GPIO14)
GPIO 20: J2.4 (RST), U1.32 (GPIO20)
GPIO 21: J2.3 (DC), U1.33 (GPIO21)
unnamed: C16.2, R5.1, Y1.1
unnamed: D1.1 (K), R11.1
unnamed: D2.1 (K), R10.1
unnamed: D3.2 (A), SW12.1 (A)
unnamed: C13.1, D3.1 (K), U5.3 (VI)
unnamed: D4.1 (K), D5.1 (K), SW12.2 (B)
unnamed: J1.A5 (CC1), R1.2
unnamed: J1.B5 (CC2), R2.2
unnamed: R3.2, U1.51 (USB_DM)
unnamed: R4.2, U1.52 (USB_DP)
unnamed: C18.1, R12.2, U1.46 (VREG_AVDD)
unnamed: L1.1, U1.48 (VREG_LX)
unnamed: R8.1, U4.2 (PROG)
unnamed: R11.2, U4.7 (~CHRG)
unnamed: R10.2, U4.6 (~STDBY)
QSPI_SCLK: U1.56 (QSPI_SCLK), U3.6 (CLK)
QSPI_SD0: U1.57 (QSPI_SD0), U3.5 (DI/IO_{0})
QSPI_SD1: U1.59 (QSPI_SD1), U3.2 (DO/IO_{1})
QSPI_SD2: U1.58 (QSPI_SD2), U3.3 (~WP/IO_{2})
QSPI_SD3: U1.55 (QSPI_SD3), U3.7 (~HOLD/~RESET/IO_{3})
QSPI_SS: R7.2, SW1.2, U1.60 (~QSPI_SS), U3.1 (~CS)
SPI0 SCK: J2.6 (SCL), U1.29 (GPIO18)
SPI0 TX/MOSI: J2.5 (SDA), U1.31 (GPIO19)
USB_5V: D5.2 (A), J1.A4 (VBUS), J1.A9 (VBUS), J1.B4 (VBUS), J1.B9 (VBUS), U4.4 (V_{CC}), U4.8 (CE)
USB_D+: J1.A6 (D+), J1.B6 (D+), R4.1
USB_D-: J1.A7 (D-), J1.B7 (D-), R3.1
XIN: C15.2, U1.21 (XIN), Y1.3
XOUT: R5.2, U1.22 (XOUT)

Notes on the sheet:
SCREEN OUTPUT
note for RUN: there used to be a button here, but its easy to just power cycle instead
Flash Memory
BATTERY MANAGEMENT
remember that everything needs to have a really closely connected capacitor from the array further up
BUTTONS
Crystal Oscillator Clock
note: the inductor footprint is 0805, not 0806, but its close enough

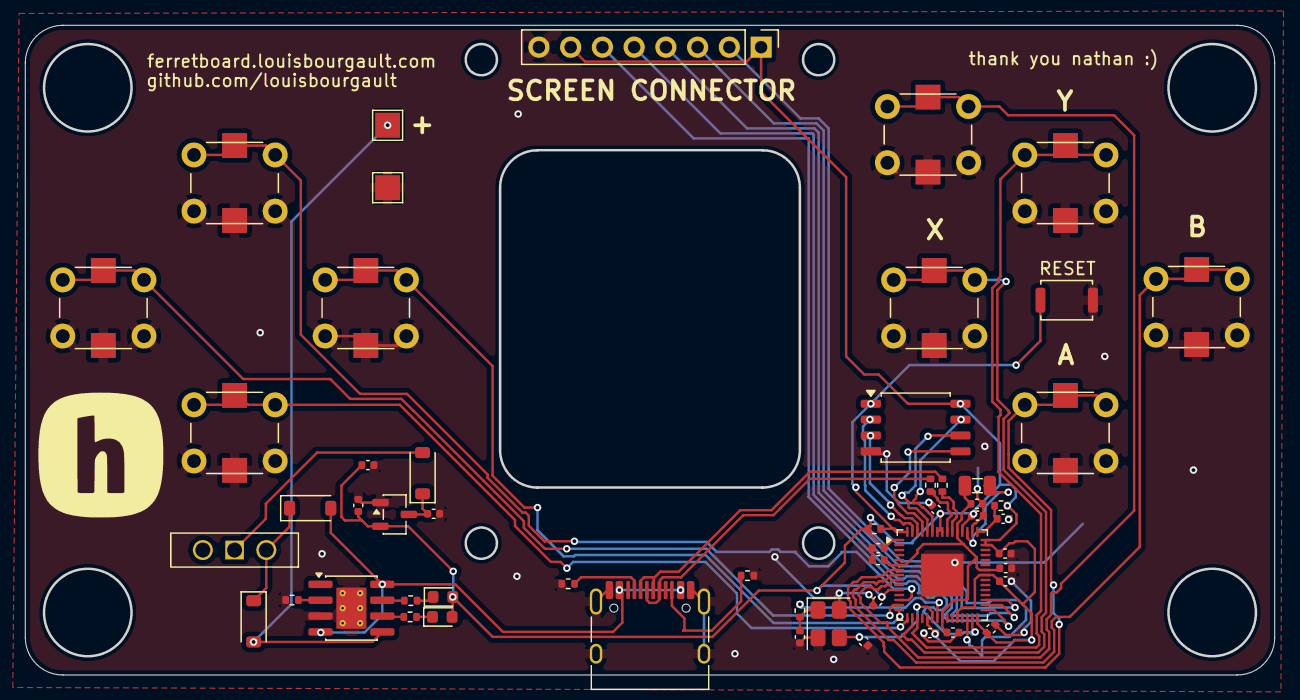
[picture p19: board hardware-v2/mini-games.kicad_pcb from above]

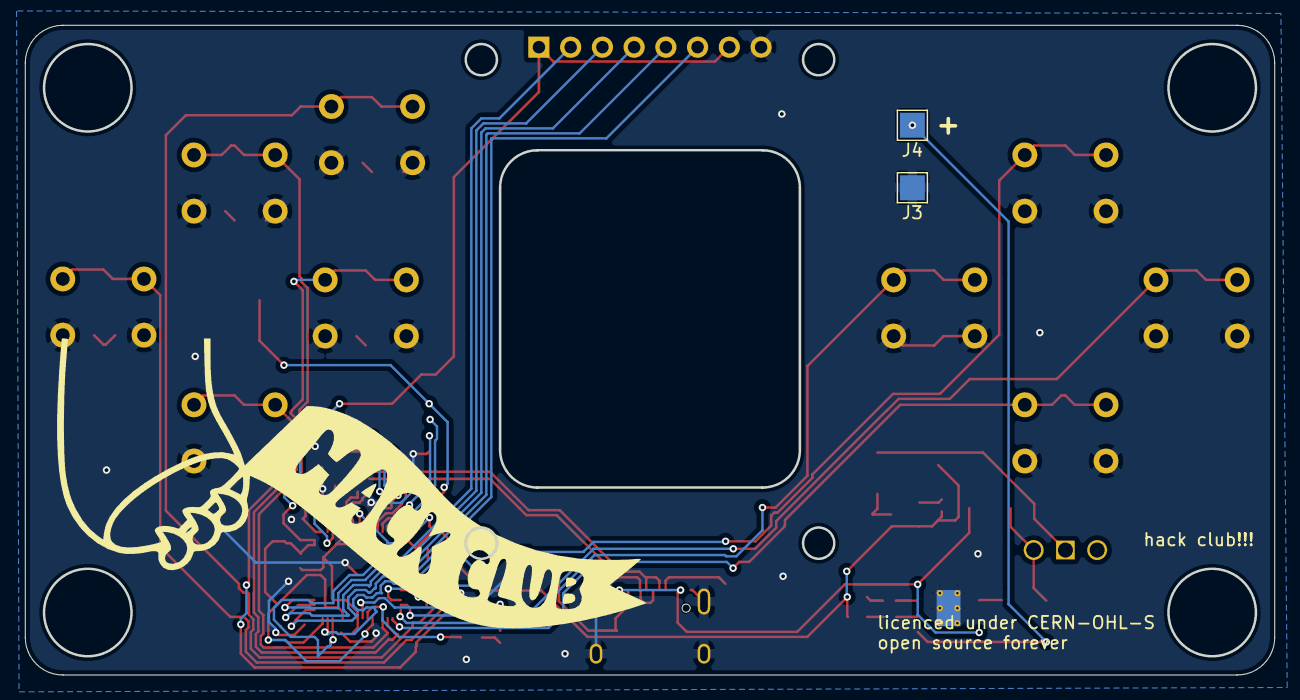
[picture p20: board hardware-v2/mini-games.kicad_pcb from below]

Board: 2 copper layers, 100.0 x 52.0 mm, 56 parts (2 on the bottom side), 44 nets.

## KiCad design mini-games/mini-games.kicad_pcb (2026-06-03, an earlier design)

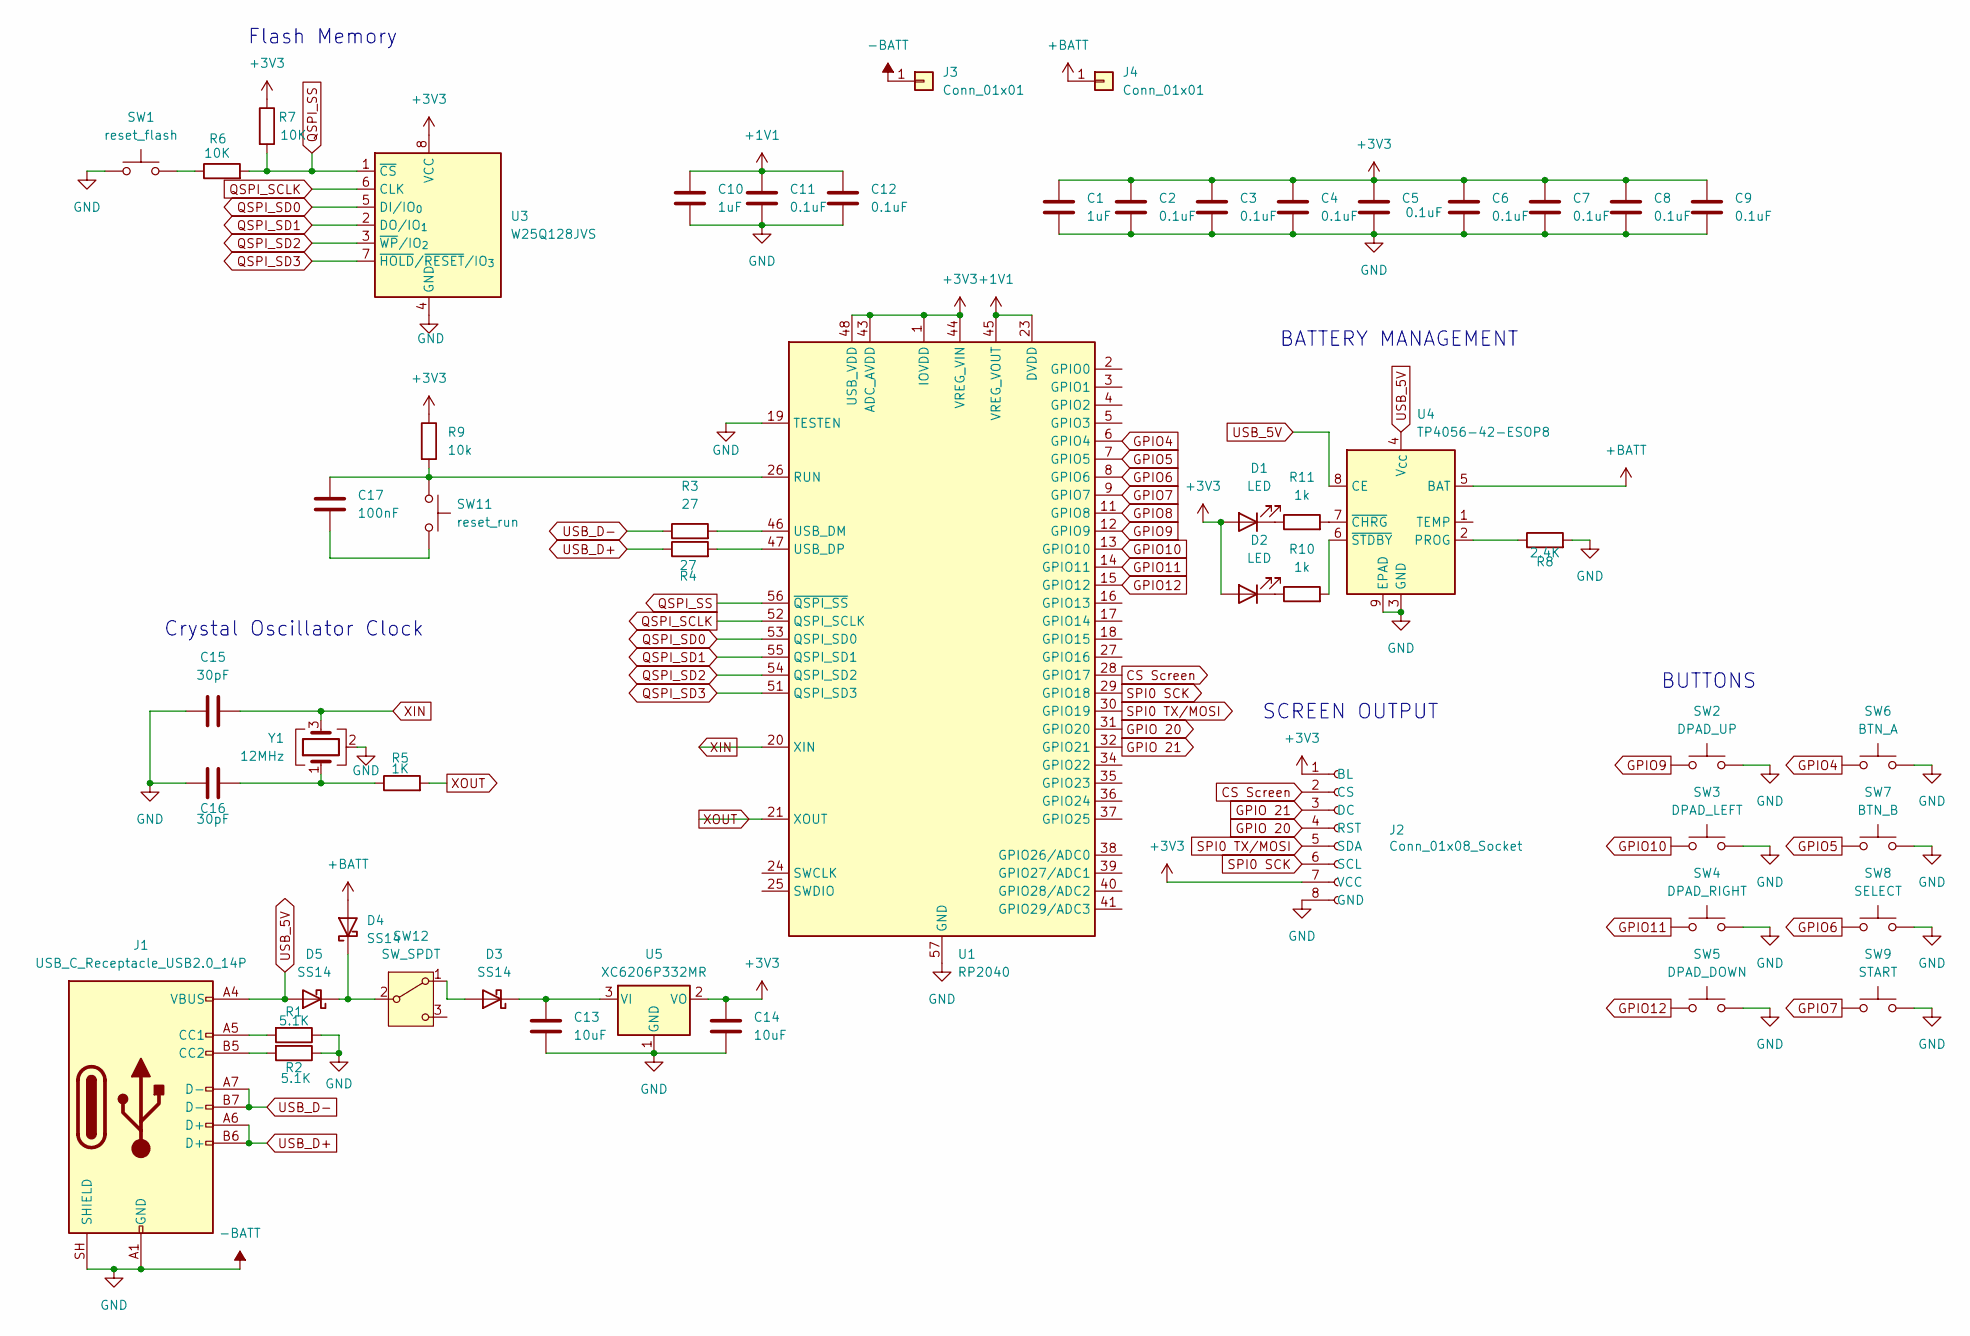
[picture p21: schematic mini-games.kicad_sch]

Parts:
C1, C10: 1uF; C_0402_1005Metric
C2, C3, C4, C5, C6, C7, C8, C9, C11, C12: 0.1uF; C_0402_1005Metric
C13, C14: 10uF; C_0402_1005Metric
C15, C16: 30pF; C_0402_1005Metric
C17: 100nF; C_0402_1005Metric
D1, D2: LED; LED_0603_1608Metric
D3, D4, D5: SS14; D_SOD-123
J1: USB_C_Receptacle_USB2.0_14P; USB_C_Receptacle_HRO_TYPE-C-31-M-12
J2: Conn_01x08_Socket; PinHeader_1x08_P2.54mm_Vertical
J3, J4: Conn_01x01; TestPoint_Pad_2.0x2.0mm
R1, R2: 5.1K; R_0402_1005Metric
R3, R4: 27; R_0402_1005Metric
R5: 1K; R_0402_1005Metric
R6, R7: 10K; R_0402_1005Metric
R8: 2.4K; R_0402_1005Metric
R9: 10k; R_0402_1005Metric
R10, R11: 1k; R_0402_1005Metric
SW1: reset_flash; SW_Push_SPST_NO_Alps_SKRK
SW2: DPAD_UP; SW_PUSH_6mm
SW3: DPAD_LEFT; SW_PUSH_6mm
SW4: DPAD_RIGHT; SW_PUSH_6mm
SW5: DPAD_DOWN; SW_PUSH_6mm
SW6: BTN_A; SW_PUSH_6mm
SW7: BTN_B; SW_PUSH_6mm
SW8: SELECT; SW_Push_SPST_NO_Alps_SKRK
SW9: START; SW_Push_SPST_NO_Alps_SKRK
SW11: reset_run; SW_Push_SPST_NO_Alps_SKRK
SW12: SW_SPDT; SW_SPDT_Shouhan_MSK12C02
U1: RP2040; QFN-56-1EP_7x7mm_P0.4mm_EP3.2x3.2mm
U3: W25Q128JVS; SOIC-8_5.3x5.3mm_P1.27mm
U4: TP4056-42-ESOP8; SOIC-8-1EP_3.9x4.9mm_P1.27mm_EP2.41x3.3mm_ThermalVias
U5: XC6206P332MR; SOT-23-3
Y1: 12MHz; Crystal_SMD_3225-4Pin_3.2x2.5mm

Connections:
+1V1: C10.1, C11.1, C12.1, U1.23 (DVDD), U1.45 (VREG_VOUT), U1.50 (DVDD)
+3V3: C1.1, C2.1, C3.1, C4.1, C5.1, C6.1, C7.1, C8.1, C9.1, C14.1, D1.2 (A), D2.2 (A), J2.1 (BL), J2.7 (VCC), R7.1, R9.1, U1.1 (IOVDD), U1.10 (IOVDD), U1.22 (IOVDD), U1.33 (IOVDD), U1.42 (IOVDD), U1.43 (ADC_AVDD), U1.44 (VREG_VIN), U1.48 (USB_VDD), U1.49 (IOVDD), U3.8 (VCC), U5.2 (VO)
+BATT: D4.2 (A), J4.1 (Pin_1_1), U4.5 (BAT)
-BATT: C1.2, C2.2, C3.2, C4.2, C5.2, C6.2, C7.2, C8.2, C9.2, C10.2, C11.2, C12.2, C13.2, C14.2, C15.1, C16.1, J1.A1 (GND), J1.A12 (GND), J1.B1 (GND), J1.B12 (GND), J1.SH (SHIELD), J2.8 (GND), J3.1 (Pin_1_1), R1.1, R2.1, R8.2, SW1.1, SW2.2, SW3.2, SW4.2, SW5.2, SW6.2, SW7.2, SW8.2, SW9.2, SW12.SH, U1.19 (TESTEN), U1.57 (GND), U3.4 (GND), U4.3 (GND), U4.9 (EPAD), U5.1 (GND), Y1.2 (G), Y1.4 (G)
CS Screen: J2.2 (CS), U1.28 (GPIO17)
GPIO4: SW6.1, U1.6 (GPIO4)
GPIO5: SW7.1, U1.7 (GPIO5)
GPIO6: SW8.1, U1.8 (GPIO6)
GPIO7: SW9.1, U1.9 (GPIO7)
GPIO8: U1.11 (GPIO8)
GPIO9: SW2.1, U1.12 (GPIO9)
GPIO10: SW3.1, U1.13 (GPIO10)
GPIO11: SW4.1, U1.14 (GPIO11)
GPIO12: SW5.1, U1.15 (GPIO12)
GPIO 20: J2.4 (RST), U1.31 (GPIO20)
GPIO 21: J2.3 (DC), U1.32 (GPIO21)
unnamed: C16.2, R5.1, Y1.1
unnamed: C17.2, SW11.2
unnamed: D1.1 (K), R11.1
unnamed: D2.1 (K), R10.1
unnamed: D3.2 (A), SW12.1 (A)
unnamed: C13.1, D3.1 (K), U5.3 (VI)
unnamed: D4.1 (K), D5.1 (K), SW12.2 (B)
unnamed: J1.A5 (CC1), R1.2
unnamed: J1.B5 (CC2), R2.2
unnamed: R6.1, SW1.2
unnamed: C17.1, R9.2, SW11.1, U1.26 (RUN)
unnamed: R3.2, U1.46 (USB_DM)
unnamed: R4.2, U1.47 (USB_DP)
unnamed: R8.1, U4.2 (PROG)
unnamed: R11.2, U4.7 (~CHRG)
unnamed: R10.2, U4.6 (~STDBY)
QSPI_SCLK: U1.52 (QSPI_SCLK), U3.6 (CLK)
QSPI_SD0: U1.53 (QSPI_SD0), U3.5 (DI/IO_{0})
QSPI_SD1: U1.55 (QSPI_SD1), U3.2 (DO/IO_{1})
QSPI_SD2: U1.54 (QSPI_SD2), U3.3 (~WP/IO_{2})
QSPI_SD3: U1.51 (QSPI_SD3), U3.7 (~HOLD/~RESET/IO_{3})
QSPI_SS: R6.2, R7.2, U1.56 (~QSPI_SS), U3.1 (~CS)
SPI0 SCK: J2.6 (SCL), U1.29 (GPIO18)
SPI0 TX/MOSI: J2.5 (SDA), U1.30 (GPIO19)
USB_5V: D5.2 (A), J1.A4 (VBUS), J1.A9 (VBUS), J1.B4 (VBUS), J1.B9 (VBUS), U4.4 (V_{CC}), U4.8 (CE)
USB_D+: J1.A6 (D+), J1.B6 (D+), R4.1
USB_D-: J1.A7 (D-), J1.B7 (D-), R3.1
XIN: C15.2, U1.20 (XIN), Y1.3
XOUT: R5.2, U1.21 (XOUT)

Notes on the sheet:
SCREEN OUTPUT
Flash Memory
BATTERY MANAGEMENT
BUTTONS
Crystal Oscillator Clock

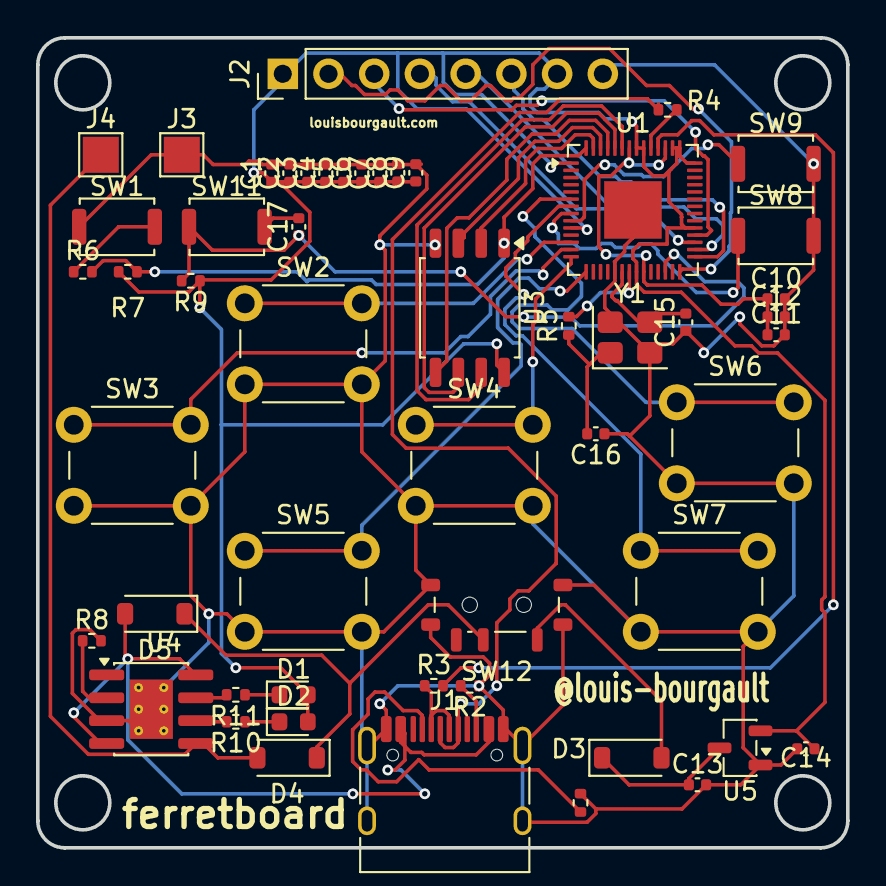
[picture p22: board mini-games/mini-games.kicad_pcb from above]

Board: 2 copper layers, 45.0 x 45.0 mm, 53 parts (0 on the bottom side), 44 nets.

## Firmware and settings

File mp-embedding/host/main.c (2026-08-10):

#include <stdint.h>
#include <string.h>

#include "py/qstr.h"
#include "py/runtime.h"
#include "py/obj.h"
#include "port/micropython_embed.h"

#include "bridge/libbridge.h"

#ifndef STATIC
#define STATIC static
#endif

static char heap[8 * 1024];

STATIC mp_obj_t mp_hello(mp_obj_t name_obj) {
    const char *name_cstr = mp_obj_str_get_str(name_obj);
    GoString name = {
        .p = name_cstr,
        .n = (ptrdiff_t)strlen(name_cstr),
    };
    say_hello(name);
    return mp_const_none;
}

STATIC MP_DEFINE_CONST_FUN_OBJ_1(mp_hello_obj, mp_hello);

STATIC void register_globals(void) {
    mp_obj_dict_store(
        MP_OBJ_FROM_PTR(&MP_STATE_VM(dict_main)),
        MP_OBJ_NEW_QSTR(qstr_from_str("say_hello")),
        MP_OBJ_FROM_PTR(&mp_hello_obj)
    );
}

int main(void) {
    int stack_top;

    mp_embed_init(&heap[0], sizeof(heap), &stack_top);
    register_globals();

    mp_embed_exec_str("say_hello('world')\n");

    mp_embed_deinit();
    return 0;
}

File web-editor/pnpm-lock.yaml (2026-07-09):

lockfileVersion: '9.0'

settings:
  autoInstallPeers: true
  excludeLinksFromLockfile: false

importers:

  .:
    dependencies:
      '@codemirror/autocomplete':
        specifier: ^6.20.3
        version: 6.20.3
      '@codemirror/commands':
        specifier: ^6.10.4
        version: 6.10.4
      '@codemirror/lang-python':
        specifier: ^6.2.1
        version: 6.2.1
      '@codemirror/language':
        specifier: ^6.12.4
        version: 6.12.4
      '@codemirror/lint':
        specifier: ^6.9.7
        version: 6.9.7
      '@codemirror/search':
        specifier: ^6.7.1
        version: 6.7.1
      '@codemirror/state':
        specifier: ^6.7.1
        version: 6.7.1
      '@codemirror/view':
        specifier: ^6.43.6
        version: 6.43.6
      '@lezer/highlight':
        specifier: ^1.2.3
        version: 1.2.3
      codemirror:
        specifier: ^6.0.2
        version: 6.0.2
      mode-watcher:
        specifier: ^1.1.0
        version: 1.1.0(svelte@5.56.4)
    devDependencies:
      '@fontsource-variable/nunito-sans':
        specifier: ^5.2.7
        version: 5.2.7
      '@internationalized/date':
        specifier: ^3.12.2
        version: 3.12.2
      '@lucide/svelte':
        specifier: ^1.23.0
        version: 1.23.0(svelte@5.56.4)
      '@sveltejs/adapter-auto':
        specifier: ^7.0.1
        version: 7.0.1(@sveltejs/kit@2.69.1(@sveltejs/vite-plugin-svelte@7.1.2(svelte@5.56.4)(vite@8.1.3(jiti@2.7.0)))(svelte@5.56.4)(typescript@6.0.3)(vite@8.1.3(jiti@2.7.0)))
      '@sveltejs/kit':
        specifier: ^2.69.1
        version: 2.69.1(@sveltejs/vite-plugin-svelte@7.1.2(svelte@5.56.4)(vite@8.1.3(jiti@2.7.0)))(svelte@5.56.4)(typescript@6.0.3)(vite@8.1.3(jiti@2.7.0))
      '@sveltejs/vite-plugin-svelte':
        specifier: ^7.1.2
        version: 7.1.2(svelte@5.56.4)(vite@8.1.3(jiti@2.7.0))
      '@tailwindcss/vite':
        specifier: ^4.3.0
        version: 4.3.2(vite@8.1.3(jiti@2.7.0))
      bits-ui:
        specifier: ^2.18.1
        version: 2.18.1(@internationalized/date@3.12.2)(@sveltejs/kit@2.69.1(@sveltejs/vite-plugin-svelte@7.1.2(svelte@5.56.4)(vite@8.1.3(jiti@2.7.0)))(svelte@5.56.4)(typescript@6.0.3)(vite@8.1.3(jiti@2.7.0)))(svelte@5.56.4)
      clsx:
        specifier: ^2.1.1
        version: 2.1.1
      paneforge:
        specifier: ^1.0.2
        version: 1.0.2(svelte@5.56.4)
      prettier:
        specifier: ^3.8.3
        version: 3.9.4
      prettier-plugin-svelte:
        specifier: ^4.1.0
        version: 4.1.1(prettier@3.9.4)(svelte@5.56.4)
      prettier-plugin-tailwindcss:
        specifier: ^0.8.0
        version: 0.8.0(prettier-plugin-svelte@4.1.1(prettier@3.9.4)(svelte@5.56.4))(prettier@3.9.4)
      shadcn-svelte:
        specifier: ^1.3.0
        version: 1.3.0(svelte@5.56.4)
      svelte:
        specifier: ^5.56.1
        version: 5.56.4
      svelte-check:
        specifier: ^4.6.0
        version: 4.7.1(picomatch@4.0.5)(svelte@5.56.4)(typescript@6.0.3)
      tailwind-merge:
        specifier: ^3.6.0
        version: 3.6.0
      tailwind-variants:
        specifier: ^3.2.2
        version: 3.2.2(tailwind-merge@3.6.0)(tailwindcss@4.3.2)
      tailwindcss:
        specifier: ^4.3.0
        version: 4.3.2
      tw-animate-css:
        specifier: ^1.4.0
        version: 1.4.0
      typescript:
        specifier: ^6.0.3
        version: 6.0.3
      vite:
        specifier: ^8.0.16
        version: 8.1.3(jiti@2.7.0)
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

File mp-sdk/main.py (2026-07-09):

from machine import Pin
import time
import os
print("files included in this run: ", os.listdir())

import modules.display as display
import modules.input as input

print("initialising display")

while True:
    input.update()
    if input.is_pressed("UP"):
        display.fill(0x0000)
    else:
        display.fill(0xFFFF)
    display.update()
    time.sleep(0.1)

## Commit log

2026-05-07 finish schematic, start pcb
    [mini-games.kicad_pcb, mini-games.kicad_sch]
2026-05-07 edit pcb, layout things and change footprints yet again
    [mini-games.kicad_pcb, mini-games.kicad_sch]
2026-05-09 categorised parts on pcb; changed one or two footprints, general improvements
    [mini-games.kicad_pcb, mini-games.kicad_sch]
2026-05-10 Finalised feature placements and routed PCB. Yet to fix errors given by DRC
    [mini-games.kicad_pcb, mini-games.kicad_sch]
2026-05-10 fixed drc critical problems
    [mini-games.kicad_pcb]
2026-05-10 added text
    [mini-games.kicad_pcb]
2026-05-11 updated, fixed more errors, ready for review i beleive!
    [mini-games.kicad_pcb]
2026-05-11 sorry, need to add this
    [mini-games.csv]
2026-05-12 add files for software and production (not current production files)
    [mini-games.kicad_pcb, mini-games.kicad_sch]
2026-05-14 updated schematic, and assigned JLC LPSC numbers in project.db ready for production. Changed some parts and footprints in order to use basic parts on JLC and avoid fees.
    [mini-games.kicad_pcb, mini-games.kicad_sch]
2026-05-14 finished pcb and exported fabrication outputs in mini-games/jlcpcb/production_files
    [BOM-mini-games.csv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]
2026-05-16 added an input system, and made a looping system with framerates (locked to 60 for now)
2026-05-17 added case files and made a copy of production files in /production
    [.step, BOM-mini-games.csv, case.f3d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]
2026-05-26 i forgot to add a step fie earlier. This is from kicad. nothing was changed, just different format
    [Case.step]
2026-05-31 removed NC connection to gnd, changed switch, ready for production!
    [BOM-mini-games.csv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]
2026-06-03 things, a basic switching between games system is in place. Anything to procrastnate actually having to code one smh
    [mini-games.kicad_pcb]
2026-06-19 seeded randomness
    [case.3mf]
2026-06-20 added physical device to website, fixed minor things in docs
2026-07-06 docs: added assembly instructions
2026-07-08 fix: general stability improvements for web editor, colour fixes for sdk
    [display.py, pnpm-lock.yaml]
2026-07-09 feat: image editor, greatly improved general editor experience, added draw image function, general other fixes and improvements
    [display.py, input.py, main.py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]
2026-08-04 made assembly instructions location more obvious
2026-08-05 Update README.md
    reproduce assembly instructions here as well
2026-08-10 feat: made a simple demo of how micropython stuff should work, hopefully it works
    [.step, mini-games.kicad_pcb, mini-games.kicad_sch]
2026-08-13 further v2 schematic drafting
    [mini-games.kicad_sch]
2026-08-14 minor: update schematic more
2026-08-15 feat: general impovements to hardware design - update button footprints, etc
    [mini-games.kicad_sch]
2026-08-16 feat: work on footprints and placing pcb things
    [mini-games.kicad_pcb, mini-games.kicad_sch]
2026-08-21 aligned all the buttons on the pcb nicely and symmetrically
    [mini-games.kicad_pcb]
2026-08-21 aligned usb and screen elements on pcb
    [mini-games.kicad_pcb]
2026-08-21 somewhat finalised locations for components, not routed yet
    [mini-games.kicad_pcb, mini-games.kicad_sch]
2026-08-21 labelling, filleting, etc - finalising placement more
    [mini-games.kicad_pcb, mini-games.kicad_sch]
2026-08-22 exported pcba, and updated to HOPEFULLY the last revision before routing
    [mini-games.kicad_pcb, mini-games.kicad_sch, pcba.step]
2026-08-22 add f3d and step for v2 case, reorganise v1 case, minor pcb updates
    [BottomCasePart.stl, Case.step, TopCasePart.stl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]
2026-08-26 work prior to today, start on clean git state for today
    [mini-games.kicad_pcb]
2026-08-26 all the routing around the 2350 done
    [mini-games.kicad_pcb]
2026-08-26 fully routed with no drc violations
    [mini-games.kicad_pcb]
2026-08-26 adding polish to board
    [mini-games.kicad_pcb]
2026-08-26 generated production files for board v2
    [BOM-mini-games.csv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]
2026-08-28 Merge in changes to embedded system (#5) tentatively
    * add firmware embed toolchain sources
    * feat: made the file system work within the embedded mp/tinygo system.
    * Add more functions
    * feat: move fs to go owned
    * Build action
    * Fix: runner
    * feat: change web editor to new API with embedded system
    * Comment out internal functions
    * fix weird image transfer
    * enabled different modules: time, math, etc
    * chore: ignore *.o embed build artifacts
    * trying to fix on image upload
    * surely, 5.6try
    * fix timer thing
    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
    [host.c, mphalport.c]
2026-08-29 added more fusion export files for the case
    [fbv2_including_pcb_and_screen.f3z, st7789_display.f3d, st7789_display.step]
2026-09-05 rp2350 fixes; editor things.
    [host.c, mphalport.c]

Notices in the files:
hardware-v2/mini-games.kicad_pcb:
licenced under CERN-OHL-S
